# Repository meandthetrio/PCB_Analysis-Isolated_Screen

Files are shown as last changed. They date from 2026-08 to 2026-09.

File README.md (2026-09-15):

# PCB Analysis — WavetableController (Daisy Seed synth)

**Read this first.** This folder holds a completed design review of Trey's "WavetableController" board — an Electrosmith Daisy Seed–based wavetable synth controller, 2-layer, 165×102 mm, designed in KiCad 9. The board has been fabbed twice at JLCPCB and the physical boards mostly work. The analysis (all passes complete, 2026-08-13) found several real defects and produced a rev-2 plan.

**If you are Claude opening this fresh:** the authoritative output is [analysis/FINAL_REPORT.md](analysis/FINAL_REPORT.md) (tiered red flags + open questions for Trey), backed by the full findings ledger F-001…F-035 in [analysis/FINDINGS.md](analysis/FINDINGS.md). Do not re-derive anything before checking those. Methodology and which-file-is-truth rules are in [analysis/SOURCE_OF_TRUTH.md](analysis/SOURCE_OF_TRUTH.md).

## Folder contents

| Path | What it is |
|---|---|
| `WavetableController.kicad_pro` / `.kicad_sch` / `.kicad_pcb` | KiCad 9 design files, sent by Trey piecemeal (see provenance below) |
| `Manifold_Gerb_LedFix/` | The Gerbers + drill files actually sent to JLCPCB ("LedFix" round, 2nd proto). **Fab truth for copper.** |
| `ManifoldRe_BOM_NEW - Excel Format.xls` | JLCPCB-format BOM |
| `analysis/` | The full review: FINAL_REPORT, findings ledger, SOURCE_OF_TRUTH, PASS1–6 reports, REV2 OLED plan, routing CSVs extracted from Gerbers, board SVG, parser script. Has its own [README](analysis/README.md) index. |
| `screen mounting solution.md` | Mechanical mounting guide for the rev-2 Crystalfontz CFAL12864G-024W COG OLED (tape+gasket sandwich, plus 3D-printed bezel alternative) |

## Critical provenance warning

Trey sent files reluctantly and in stages: Gerbers+BOM first, then .pro/.sch, then the .kicad_pcb last. File mtimes are transfer times, not edit times. The `.kicad_pcb` in this folder matches the LedFix Gerbers ~97% **but contains NO GND pour** (only 5 keepout zones), while the fabbed B.Cu Gerber has a 164×100 mm filled pour covering 44/63 GND pads. It is a stale/wrong version — **never regenerate Gerbers from this copy.** Standing ask: get Trey's real working .kicad_pcb (the one that shows a filled B.Cu pour when opened). Where sch and pcb disagree (e.g. LED2 wiring), the pcb matches the fabbed boards, so the schematic is the outlier.

## Headline findings (details + evidence in analysis/)

- **Encoder push-buttons dead** — ENCL_CLICK / ENCR_CLICK have zero copper in the Gerbers (floating inputs; ENCR lands on a 3.3V-only Daisy pin). Fab-confirmed.
- **RGB LEDs triple-broken** — LED1/LED2 (CLS6B-FKW) are unplaced (missing from BOM, though the paste stencil expects them), reverse-biased via 300Ω to +9V_FILT (never light either polarity), and three LED pins sit on Daisy's 3.3V-only pins 24/25/30.
- **I2C has zero pull-ups in-design** — the ~203 mm bus relies entirely on the OLED module's onboard pull-ups (open question F-027 for Trey).
- **Duplicate refdes R21** — a layout-only 300Ω footprint at (170.1, 84.8) bridges /OLED_HOT–/+3V3_D in parallel with FB4 (Trey's noise-debug hack, on physical boards, not in schematic). Pick-and-place would put 300Ω where the 10Ω OLED damper belongs; breaks BOM/CPL matching.
- **0.1 mm traces board-wide** — exactly AT JLCPCB's 2-layer 1oz minimum (not below it), zero margin; carries the +3V3_D rail, I2C, SD, MIDI, USB. Recommend 0.2–0.25 mm. DRC min_track_width is 0.0 in the .kicad_pro, so KiCad won't flag them.
- **BOM refdes mismatch** — BOM's S1/S2 don't exist in the schematic (real refs are TAC_SWITCH_1/2, TAC_SHIFT_L1/R1 — note: underscore refs escape `[A-Z]+[0-9]+` regexes).
- 3 marginal fab violations (MK1 annular ring, P2 NPTH clearance, SW1 edge copper — the last is a deliberate notch, accepted). Power design: USB-C is data-only by design; 9V barrel → Schottky bridge → +9V_FILT (~8.3V).

**Open questions blocked on Trey:** F-014 (LED2 sch-vs-pcb, which is intended), F-027 (OLED module pull-up value), and the real .kicad_pcb with the GND pour.

## Rev-2 screen work (planning only, no design files changed)

[analysis/REV2_OLED_PLAN.md](analysis/REV2_OLED_PLAN.md): replace the two HiLetgo SSD1309 modules (boost-coil whine) with bare COG panels on 0.5 mm ZIF, independent I2C addresses 0x3C/0x3D. Two candidate panels:

- **Mono:** Crystalfontz CFAL12864G-024W (2.4", SSD1309) — needs 12.5–13.5V VCC, so a 15V adapter + ~13V LDO. Mounting solved in `screen mounting solution.md`.
- **Greyscale (user's preference):** no 2.42" greyscale panel exists anywhere. Best match is Raystar REX012864U / Winstar WEO012864U — 2.7" SSD1357, 16-level grey, VCC 8–10.5V (12V adapter + 10V LDO). **Unresolved geometry flag:** two 73 mm glasses = 146 mm side-by-side and conflict with the x≈165–200 audio-corridor keep-out. Fallback: stay mono, or 1.54" SSD1327.

Board changes either way: add 2.2k I2C pull-ups, remove J2/FB4/C14/C17/both R21s, use Daisy spare pads 22 & 28 for RES# and VCC_EN sequencing.

## Tooling notes

- **KiCad 9.0.9 (Linux / Claude Code on the web):** `kicad-cli` and the `pcbnew` Python module are on PATH. `.claude/hooks/session-start.sh` (a SessionStart hook) runs `tools/kicad_env_setup.sh` automatically in web sessions; run it by hand with `sudo tools/kicad_env_setup.sh` elsewhere. It installs the stock symbol/footprint libs and seed the user library tables (otherwise ERC/DRC add ~190 "library not found" warnings). `tools/kicad_check.sh` runs ERC, DRC, netlist, Gerber, SVG and PDF exports into `kicad_out/` (git-ignored) as a smoke test.
- **Freerouting 2.4.1 autorouter** is installed by the same setup script (needs Java 25, installed alongside the system Java 21; `freerouting` wrapper on PATH runs it headless with analytics off). `tools/autoroute.py IN.kicad_pcb OUT.kicad_pcb [--passes N]` does DSN export → route → SES import. It temporarily renames the duplicate R21, because the Specctra exporter refuses boards with duplicate refdes (an independent confirmation of that finding). On the stale checked-in board, 2 passes took 53 unrouted connections to 5. Remaining lib warnings name Trey's private libs (`Retroactive_Custom_Parts`, `Jack_3.5mm_CUI_RetroactiveCustom`, `SOP-6_...(RetroactiveCustom)`), which only exist on his machine; footprints are embedded in the `.kicad_pcb`, so they are harmless. Note `pcbnew.LoadBoard(...).Zones()` returns 0 here because the 6 keepout zones live inside footprints, not at board level.
- On Trey's Mac, KiCad 10.0.5 lives at `/Applications/KiCad.app` (kicad-cli at `Contents/MacOS/kicad-cli`; brew cask fails without sudo).
- `analysis/gerber_analyze.py` is the Gerber parser/net-matcher that produced the routing CSVs. Other scratch scripts (pcb_parse.py, pcb_audit.py, DRC/ERC reports) lived in a session scratchpad and may be gone — regenerate from gerber_analyze.py patterns if needed.
- Net names in the routing CSVs are geometrically inferred (anchored at Daisy pins, 6/6 validated on LED nets), not authoritative; `island_*` = unidentified copper.

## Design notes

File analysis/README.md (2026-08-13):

# Analysis folder index

Start here: **`FINAL_REPORT.md`** — the tiered red-flag summary, including the three open questions for Trey. Everything else is supporting material; no findings live only in this README.

## Reports
- `FINAL_REPORT.md` — final summary, Tiers 1–4, questions for Trey
- `FINDINGS.md` — full ledger (F-001…F-035) behind the summary
- `HIGH_LEVEL_PLAN.md` — the pass plan the review followed
- `SOURCE_OF_TRUTH.md` — methodology: which file is authoritative for what, verification rules
- `PASS1_FAB_CONSTRAINTS.md` … `PASS6_MECHANICAL.md` — per-pass detail (fab limits, power, connectivity, BOM, signals, mechanical)
- `REV2_OLED_PLAN.md` — OLED/I2C rev-2 planning

## Data files (derived, machine-generated)
Extracted from the fabbed Gerbers, with net names assigned by geometrically cross-referencing copper connectivity against the schematic netlist (anchored at Daisy Seed pins). Net attribution is inferred, not authoritative — `island_*` entries are copper the matcher could not identify.
- `routing_tracks.csv` — every track segment: layer, endpoints, width, length, net
- `routing_pads.csv` — pads: layer, position, shape, size, net
- `routing_vias.csv` — vias: position, drill, pad, net
- `wavetable_board.svg` — rendered board view from the Gerbers
- `gerber_analyze.py` — the parser/matcher script that produced the above

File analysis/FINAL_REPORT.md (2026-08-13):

# WavetableController — Final Red-Flag Report
**Date:** 2026-08-13 · **Scope:** Passes 0–6 complete (see `HIGH_LEVEL_PLAN.md`), 35 ledger entries (`FINDINGS.md`), all verified per `SOURCE_OF_TRUTH.md` — every measurement scripted, every threshold fetched and cited.
**Verification state:** 33 of 35 findings confirmed; 2 blocked on information only Trey has (marked ⏳ below). Nothing remains unverified-and-unflagged.

---

## Tier 1 — Defects in the working boards (physical, today)

**1. Encoder click switches are dead.** (F-007, fab-truth confirmed)
No copper exists at any of the four click-switch pad sites on either layer of the fabbed Gerbers. Both encoder push-inputs float. If firmware reads them, behavior is undefined. *Fix: route ENCL1.S1→pin 11, ENCR1.S1→pin 29 (pin 29 is 3.3V-only — never pull above 3V3).*

**2. The RGB LEDs are broken three ways.** (F-001/F-018/F-002/F-034)
(a) Not placed: the only SMD parts missing from the BOM — while the top-side paste stencil contains exactly their 12 apertures. (b) Wired to never light: permanently reverse-biased (anodes on GPIOs, cathodes toward +9V via 300Ω). (c) Hazardous if placed: 5.7–9V reverse across dice rated ~5V, and three of the six GPIOs (Daisy pins 24/25/30) are on the datasheet's 3.3V-only list — an avalanche event injects current into non-tolerant pins. *Fix: rewire GPIO→resistor→LED→GND per the Daisy reference (Fig 1.8), resize resistors for 3.3V, add LEDs to BOM.*

**3. The I2C/OLED subsystem stands on two hidden crutches.** (F-019 confirmed + F-027 ⏳)
The 203mm I2C bus has **zero pull-up resistors in the design** — it works only because of undocumented pull-ups presumed on the OLED module. And the +3V3_D rail feeding SD+OLED+MIDI has a single 100nF cap, with the SD card 109.5mm (~0.5Ω of 0.1mm trace) from it. Together these are the causal chain behind the OLED/I2C noise that was historically patched with a ferrite + 470µF + hand-added 10Ω. *Fix: explicit 2.2–4.7k pull-ups; 100nF+10µF at the SD connector; wider 3V3_D trunk. ⏳ Ask Trey what pull-ups the OLED module carries.*

## Tier 2 — Landmines that fire on the NEXT build (files as they stand)

**4. The `.kicad_pcb` in hand has no ground plane.** (F-006)
Provably not the file that made the working Gerbers (which contain a 164×100mm B.Cu pour this file cannot produce). Re-plot from it and you ship a board with 51 floating GND connections. *Fix: get Trey's real working file, or re-create the GND zone before any re-plot.*

**5. Duplicate refdes R21 → automated mis-build.** (F-013/F-025)
Two R21s on the PCB (300Ω LED resistor + 10Ω OLED damper); the BOM's only R21 line is 300Ω. Pick-and-place from this board puts **300Ω in the OLED's power feed** (30× intended). *Fix: rename the damper (e.g., R29), give it its own BOM line.*

**6. Board-level fixes were never back-annotated.** (F-020/F-014 ⏳)
The 10Ω OLED damper exists only in the PCB; the schematic doesn't know about it. LED2's pin-wiring differs between schematic and PCB (PCB matches the fabbed Gerbers; the schematic is the outlier). Any respin driven from the schematic silently reverts both. *⏳ Reconcile against Trey's current working files.*

**7. BOM S1/S2 can't be built.** (F-003)
An SMD 6×6mm tactile switch (C2835239) with no matching board position — the board's tactile switches are all through-hole. Stale line or diverged part choice; an assembler will flag or skip it.

## Tier 3 — Fab-margin risks (absorbed by tolerance so far)

**8. 3.85 meters of trace at exactly the 0.10mm minimum** (F-004/F-012) — zero margin against JLCPCB's ±20% width tolerance, including the 3V3_D power rail. Not a violation; the defining latent risk of the layout. *Widen to ≥0.2mm on respin; note 2oz copper would make 0.1mm illegal (min 0.16).* 
**9. Three marginal spec violations, fabbed OK twice** — MK1 annular ring 0.175mm vs 0.18 absolute min (F-016); USB-C footprint NPTH-to-copper 0.194 vs 0.20mm (F-008); SW1 edge copper in its deliberate notch, 0.0 vs 0.2mm — accepted (F-010). *Footprint edits when convenient; a stricter fab lot could reject any of them.*

## Tier 4 — Robustness & hygiene (JUDGMENT)

- **Headphone amp missing its datasheet-recommended ≥10µF bulk cap** on 3V3_A (F-031, TI SLOS314B cited; mid-rail bypass check passes).
- **No chassis mounting holes** — board hangs from panel hardware; confirm the enclosure plan (F-032).
- Long thin analog runs (up to 285mm @ 0.1mm) — fine as built, shorten on respin (F-030). USB pair asymmetry — benign at Full-Speed (F-028). SD card-detect half-wired, unusable by firmware (F-022). ERC hygiene: 13 missing no-connect flags + 2 PWR_FLAGs would take ERC to zero (F-024). Hand-assembly parts (incl. the 470µF noise-fix cap) exist on no list (F-026). Silk warnings = panel artwork, cosmetic (F-033). DRC minimums zeroed in the project file — set to JLC values so KiCad guards the margins (F-005).

## What passed (verified, cited)
Power-entry topology (9V within VIN 4–17V; D2–D5 bridge); AGND↔DGND tie; SD interface incl. reference-design 47K pullups; MIDI in/out exactly per 3.3V MIDI practice; all rails within IPC-2221 ampacity; via geometry (0.6/0.3mm, wide margin); all drill sizes; hole-to-hole spacing; copper spacing; courtyards (zero overlaps); mask consistency; BOM values (58/58 designators consistent).

## The three questions for Trey
1. Send the **current working `.kicad_pcb`** — the one that shows a filled bottom ground pour when opened (this copy has none).
2. **What pull-ups are on the OLED module?** (determines whether I2C stands on anything at all)
3. Is the **schematic or the PCB** right about LED2's wiring — and does your schematic have the 10Ω OLED damper the PCB carries as a second "R21"?

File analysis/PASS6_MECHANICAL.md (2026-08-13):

# Pass 6 — Mechanical & Assembly Report
**Date:** 2026-08-13 · **Truth checked:** `.kicad_pcb` geometry + Gerber paste/mask/silk + DRC baseline

## Board
165.1 × 101.6mm bounding box (matches the ~165×102 expectation), 1.6mm, outline is a polygon (not a plain rectangle — see SW1).

## F-010 RESOLVED: SW1 edge copper is deliberate
SW1 is a vertical **slide switch** (DigiKey 1101A4VQEA) at the top edge; its no-net anchor pads sit 0.41mm from the board's bounding box, but the Edge.Cuts **polygon notches inward** at the switch so the outline reaches the pads (DRC's 0.000mm). This is a deliberate edge-mount: the actuator needs the notch. Reclassified **JUDGMENT — accepted design deviation**: still technically below JLCPCB's 0.2mm copper-to-edge spec, fab-proven twice; expect occasional burrs/exposed copper at the notch. No action unless a fab rejects it.

## F-032 (NEW — JUDGMENT): no chassis mounting holes
Every NPTH on the board is a component alignment post: 5×1.2mm under each of the five 3.5mm jacks (25), 2.0mm at the barrel jack, 2×0.65mm at USB-C. There are **no M2.5/M3 mounting holes**. For a synth control surface this usually means the board hangs entirely from panel hardware (jack bushings, encoder nuts, switch bushings) — workable, but all mechanical stress from cable insertions transfers through solder joints and panel nuts. Confirm the enclosure plan; if the board isn't nut-mounted to a panel, this is a real gap.

## F-033 (NEW — JUDGMENT/cosmetic): silkscreen findings are panel artwork
The 143 silk warnings decompose as: 62 = front-silk **artwork polygons** (the 88 gr_polys — this board's front silk is the control-panel graphics) over copper, 37 = artwork reaching the board edge, 32 overlaps among art/refdes (ENCR1, TAC_SWITCH_2, LED2 etc.), 7 = SW1's back-silk over copper. Fabs clip silk on exposed pads automatically; over-masked-copper silk prints fine. Cosmetic — worth one visual check of the fab's silk preview on the next order, nothing more.

## F-034 (NEW — corroborates F-002): the stencil expects the missing LEDs
Paste flash counts: **F.Paste = 12 flashes — exactly the 12 pads of LED1+LED2** (the only top-side SMD parts); B.Paste = 192 (all other SMD, bottom side). So the top stencil and placement data anticipate the LEDs that the BOM omits — the assembly gap is physical, not just clerical: paste gets printed (if a top stencil was ordered) for parts that never arrive.

## Clean checks
- **Courtyard overlaps: zero** (severity-all DRC reported none) — PASS.
- **Mask layers consistent**: F/B mask flash counts (151/321) consistent with pad+via tenting config — PASS.
- **Connector accessibility**: jacks/encoders/switch all on top face with bushings at or near edges (panel-through design) — consistent with F-032's panel-mount assumption.
- Hole-to-hole, edge clearances (other than SW1), drill ranges: all covered and passed in Pass 1.

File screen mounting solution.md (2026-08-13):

# Screen Mounting Solution — Crystalfontz CFAL12864G-024W OLED

**Module:** [CFAL12864G-024W](https://www.crystalfontz.com/product/cfal12864g024w-128x64-2-4inch-white-oled-module) — 128×64 2.4" white OLED
**Context:** Bare chip-on-glass (COG) module mounted between a PCB and a metal enclosure with a display cutout.

## Key mechanical facts

| Property | Value |
|---|---|
| Glass outline | 60.5 × 37.0 mm |
| Thickness | 2.15 mm |
| Viewing area | 57.01 × 28.91 mm |
| Active area | 55.01 × 27.46 mm |
| Weight | 9.2 g |
| Connection | FPC ribbon tail into ZIF connector (TE 3-1734839-1 top-contact, or Hirose FH41-31S-0.5SH bottom-contact) |
| Mounting holes | **None** — cannot be screwed down |

## Mounting approach: tape + gasket sandwich

### 1. Adhesive tape to the PCB (primary attachment)
- Frame of thin double-sided adhesive on the PCB where the glass sits:
  - 3M 467MP / 468MP transfer tape (thin), or 3M VHB (adds cushioning)
- Keep-out under the active area — no components or vias under the glass, or add a spacer/foam pad to keep it flat.
- FPC tail folds around into the ZIF connector on the PCB.
- The tape IS the mount — this is how nearly every product using these glass modules does it.

### 2. Foam gasket between glass and metal panel
- Rectangular picture-frame gasket, ~0.5–1 mm compressible foam, around the display opening on the inside of the enclosure.
  - Poron is the classic choice; 3M double-coated foam tape (e.g. 4926) also works.
- When the enclosure closes, the foam lightly compresses against the glass face.
- Four jobs: takes up stack-height tolerance, prevents glass-to-metal contact (glass + rigid metal = cracked display), blocks light leakage around the window, keeps dust out.

### 3. Window sizing
- Bezel opening: bigger than viewing area (57.0 × 28.9 mm), smaller than glass outline (60.5 × 37 mm).
- ~**58 × 30 mm** hides the glass edges and the driver-chip strip while showing the full image.
- The active area is offset toward one side of the glass (driver IC + FPC take up one edge) — center the window on the *viewing area* from the datasheet drawing, not on the glass outline.

## Stack-height calculation

Measure: PCB top surface → inside face of enclosure panel.

```
gap − 2.15 mm (glass) = tape thickness under glass + compressed foam thickness above it
```

- If the gap is large: rigid spacer or 3D-printed carrier frame under the display, keep the foam layer thin.
- Target ~30–50% foam compression — gentle, even pressure only around the border of the glass, never concentrated on a corner.

## Cautions

- **Don't** rely on enclosure clamping alone — vibration lets the glass shift and the FPC fatigues.
- **Don't** hard-clamp the glass rigidly with no compliance — it needs the foam.
- Alternative for serviceability: small 3D-printed or machined bezel frame that captures the glass edges and screws to the PCB (detailed below). For one-offs / small runs, tape + Poron gasket is the proven answer.

## Alternative: 3D-printed bezel frame

A rectangular frame that screws to the PCB and captures the glass — serviceable (no adhesive), precisely located, and sets the correct height to the enclosure window. The glass drops into a pocket from behind; the front lip overhangs the glass edges; the frame screws to the PCB trapping the glass — always with thin foam in the sandwich, never plastic clamped hard on glass.

### Design dimensions

| Feature | Dimension | Notes |
|---|---|---|
| Glass pocket | 61.0 × 37.5 mm | +0.5 mm total clearance over the 60.5 × 37.0 glass; drop-in fit, never press-fit |
| Pocket depth | ~2.0 mm | Glass is 2.15 mm — lip pre-loads slightly onto foam instead of bottoming plastic-on-glass |
| Front lip opening | ~58 × 30 mm | ~1.5 mm overlap per side; larger than 57.0 × 28.9 viewing area so no image crop; hides driver-chip strip |
| FPC slot | Full ribbon width | In the pocket wall on the FPC edge (check datasheet drawing); round/chamfer edges so ribbon doesn't crease when folding to the ZIF |
| Foam | 0.5 mm Poron | Between lip and glass face, ideally also under the glass. Foam grips the display; plastic only sets geometry |
| Mounting | 4× corner bosses, M2 | Heat-set inserts (clean) or M2 self-tappers into 1.7 mm holes. Add matching M2 holes to the PCB around the display footprint |

- The active area is **offset** on the glass — model the opening relative to the viewing area per the datasheet mechanical drawing, not the glass outline.
- Nice extra: alignment pins or a raised rim on the front face that registers into the enclosure window cutout — the screen self-centers and PCB↔enclosure tolerance stacking disappears.

### Printing notes

- **Material:** PETG or ASA. PLA OK for prototypes but creeps under clamping load and softens in a warm enclosure.
- **Orientation:** bezel-face-down on a smooth plate — clean visible face, no supports needed for the pocket.
- **Tolerances:** FDM pockets come out 0.1–0.3 mm undersized. Print just the pocket as a quick test piece and confirm the glass drops in before printing the full frame.
- **Caution:** no plastic may press directly on glass anywhere — every contact on the display face goes through foam. Glass tolerates gentle distributed pressure, fails at hard point contacts.

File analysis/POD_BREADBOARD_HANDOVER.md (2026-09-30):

# Handover: Newhaven OLED breadboard test on a Daisy Pod

*Written 2026-09-30 for a new, separate firmware repo. Source of the decisions below:
`analysis/REV2_OLED_PLAN.md` §11 in the PCB_Analysis-Isolated_Screen repo.*

Copy this file, the Newhaven datasheet PDF (`NHD-2.7-12864WDW3-3.pdf`), and Trey's pin
list (`OLED_Pin_Connects_to_Newhaven.txt`) into the new repo's `docs/` folder.

---

## 1. What we are doing and why

**Project:** WavetableController, a Daisy Seed based synth controller (Trey's board).
Rev 1 uses a HiLetgo 2.42" SSD1309 OLED module over I2C. Its on-board boost converter
causes audible coil whine and couples noise into the audio path. Rev 2 replaces it.

**New screen:** Newhaven **NHD-2.7-12864WDW3** — 2.7" 128×64 white OLED module,
**SSD1322** controller (16-level grayscale), **4-wire SPI**, 1×20 pin 2.54 mm header.
It is a module on its own PCB, not bare glass.

**This phase:** prove the screen works with the Daisy platform before any PCB changes.
Concretely:

1. Wire the module to a **Daisy Pod** on a breadboard.
2. Write a small libDaisy program that initialises the SSD1322 over SPI and draws
   something recognisable (text / rectangle / test pattern).
3. Confirm the SPI pin assignment that the rev-2 board will use, unchanged.

The existing firmware's SSD1309 driver does **not** carry over. SSD1322 is a different
command set and a 4-bit-per-pixel framebuffer. libDaisy has no SSD1322 driver; its
`src/dev/oled_ssd1327.h` (also 4-bit grayscale) is the closest reference.

**Deliberate constraint:** the screen's five signal pins are **identical on the Pod and on
the rev-2 PCB**. The screen is the new/complex element, so it keeps fixed pins and the
simple things (encoders, buttons) move around it on the board. Do not "just use any free
pin" on the Pod — use the table in §3.

---

## 2. Power for this test (decided)

**Default jumpers, everything from 3.3 V.** Module as shipped: R4 closed, R5 open,
R7 open. Pin 2 (VDD) gets 3.3 V; the module's on-board boost makes the panel voltage.
Pins 3 and 15 stay open. Pin 18 (/SHDN) stays open (internally pulled high → boost on).

Datasheet (p.6, Default Jumper Setting): VDD 3.0–3.5 V, **IDD 345 mA typ / 375 mA max
at 100 % pixels on**.

We could not find a published current limit for the Seed's 3V3 output (its datasheet
doesn't state one). To keep the test safe regardless:

- Power the Pod from a **USB wall adapter ≥ 1 A**, not a laptop USB port (500 mA budget
  is already exceeded by Seed + Pod + screen).
- **Do not run the all-pixels-on test (0xA5).** That is the 375 mA case. Normal UI
  content (10–30 % pixels) draws roughly proportionally less.
- **Start with master contrast reduced**: command `0xC7` with data `0x03` (¼ output)
  instead of the datasheet's `0x0F`. Raise later once current is known.
- Draw text / outlines, not filled screens.
- Feel the Seed's regulator after a minute. Warm is fine; too hot to hold is stop.
- Decouple pins 2→1 at the header: 100 nF + 10–100 µF. The boost pulls current in bursts
  and breadboard rails are poor.

Later (not this test): jumper option #2 feeds the panel from an external 14.5–15.5 V on
pin 15 and disables the boost. That is the rev-2 noise fix; it is a separate experiment.

---

## 3. Wiring: Newhaven module → Daisy Pod (20 pins)

From the datasheet serial-interface pin table (p.4) and interface-select table (p.5).
Seed pin = the 40-pin physical numbering on the Seed / Pod headers.

| Module pin | Symbol | Connect to | Notes |
|---|---|---|---|
| 1 | VSS | GND | |
| 2 | VDD | **3.3 V** (Seed pin 38, 3V3_D) | + decoupling caps, see §2 |
| 3 | NC (BC_VDD) | open | |
| 4 | D/C | **D11** = Seed pin 12 (PB8) | 0 = command, 1 = data |
| 5 | VSS | GND | |
| 6 | VSS | GND | |
| 7 | SCLK | **D8** = Seed pin 9 (PG11, SPI1_SCK) | |
| 8 | SDIN | **D10** = Seed pin 11 (PB5, SPI1_MOSI) | |
| 9 | NC | open | |
| 10 | VSS | GND | |
| 11 | VSS | GND | |
| 12 | VSS | GND | |
| 13 | VSS | GND | |
| 14 | VSS | GND | |
| 15 | NC (VCC) | open | (15 V input, only with jumper option #2) |
| 16 | /RES | **D12** = Seed pin 13 (PB9) | active low; optional 10 k pull-down to GND |
| 17 | /CS | **D7** = Seed pin 8 (PG10, SPI1_NSS) | active low |
| 18 | /SHDN | open | internally pulled high |
| 19 | BS1 | GND | BS1 = 0, BS0 = 0 → 4-wire SPI |
| 20 | BS0 | GND | |

No pull-up resistors are needed (SPI is push-pull). Nothing above 3.3 V anywhere.

**These five pins are the rev-2 board assignment too:** D7 /CS, D8 SCLK, D10 SDIN,
D11 D/C, D12 /RES. On the board, /ENCR_A, /ENCR_B and /ENCL_CLICK move off D7/D8/D10
to make room.

---

## 4. Daisy Pod pin usage (Pod Rev 3/4 on Seed Rev 3/4)

From libDaisy `src/daisy_pod.cpp`, `src/daisy_seed.h`, `src/per/uart.cpp`.
Seed digital pin numbering: D0–D14 = physical pins 1–15; D15–D30 = physical pins 22–37.

### Used by the Pod

| libDaisy | STM32 | Seed pin | Pod function |
|---|---|---|---|
| D13 | PB6 | 14 | Encoder click (also USART1_TX, unused: no MIDI out) |
| D14 | PB7 | 15 | MIDI in (USART1_RX) |
| D15 | PC0 | 22 | Knob 2 (ADC) |
| D17 | PB1 | 24 | LED 2 red |
| D18 | PA7 | 25 | LED 1 blue |
| D19 | PA6 | 26 | LED 1 green |
| D20 | PC1 | 27 | LED 1 red |
| D21 | PC4 | 28 | Knob 1 (ADC) |
| D23 | PA4 | 30 | LED 2 blue |
| D24 | PA1 | 31 | LED 2 green |
| D25 | PA0 | 32 | Encoder B |
| D26 | PD11 | 33 | Encoder A |
| D27 | PG9 | 34 | Button 1 |
| D28 | PA2 | 35 | Button 2 |
| — | — | 16–19 | Audio in/out L/R (codec) |
| D29 / D30 | PB14 / PB15 | 36 / 37 | USB D− / D+ |

Fixed: pins 20 and 40 GND, 21 3V3_A, 38 3V3_D, 39 VIN.

### Free on the Pod

| libDaisy | STM32 | Seed pin | Note |
|---|---|---|---|
| D0 | PB12 | 1 | USB_ID, usable GPIO |
| D1–D6 | PC11, PC10, PC9, PC8, PD2, PC12 | 2–7 | SDMMC pins (no SD slot on Pod) |
| **D7** | **PG10** | 8 | **SPI1_NSS → screen /CS** |
| **D8** | **PG11** | 9 | **SPI1_SCK → screen SCLK** |
| D9 | PB4 | 10 | SPI1_MISO (unused; screen is write-only) |
| **D10** | **PB5** | 11 | **SPI1_MOSI → screen SDIN** |
| **D11** | **PB8** | 12 | **→ screen D/C** |
| **D12** | **PB9** | 13 | **→ screen /RES** |
| D16 | PA3 | 23 | free (ADC-capable) |
| D22 | PA5 | 29 | free (3.3 V-only pin) |

The Pod's knobs, buttons, encoder, LEDs and MIDI are all untouched by the screen wiring.

---

## 5. SSD1322 / firmware facts needed to write the program

### libDaisy transport already fits

`libDaisy/src/dev/oled_ssd130x.h` contains `SSD130x4WireSpiTransport`. Its **defaults are
exactly our pins**: SPI1, SCLK PG11 (D8), MOSI PB5 (D10), NSS PG10 (D7), hardware NSS,
TX-only, 8-bit, mode 0. Only `pin_config.dc` and `pin_config.reset` need overriding to
PB8 (D11) and PB9 (D12). Its `SendCommand()` / `SendData()` handle the D/C line. Reuse it;
write only the SSD1322 init and framebuffer code. Set `baud_prescaler` to `PS_32` or
slower to start (few MHz); SSD1322 SPI limit is ~10 MHz.

### Reset timing (datasheet p.15)

/RES low ≥ 200 µs → high → wait ≥ 200 µs → send commands. (The libDaisy transport's
`Init()` does 10 ms each side, which is fine.)

### Init sequence (datasheet p.15, Newhaven's own routine, verbatim)

```
0xAE              display OFF
0xB3 0x91         clock divide / oscillator
0xCA 0x3F         MUX ratio 64
0xA2 0x00         display offset
0xAB 0x01         function select: internal VDD regulator
0xA0 0x16 0x11    re-map (nibble remap + dual COM mode)
0xC7 0x0F         master contrast   ← use 0x03 for the first test (see §2)
0xC1 0x9F         contrast current
0xB1 0xF2         phase length
0xBB 0x1F         pre-charge voltage
0xB4 0xA0 0xFD    VSL / display enhancement
0xBE 0x04         VCOMH
0xA6              normal display
0xAF              display ON
```

Then to write pixels:

```
0x15 0x1C 0x5B    column address window 28..91
0x75 0x00 0x3F    row address window 0..63
0x5C              write RAM, then stream data bytes
```

### Framebuffer format (derived from the datasheet mechanical drawing, Detail A; verify
against Newhaven's example code at github.com/newhavendisplay before trusting it)

- The SSD1322 has 480 segments × 128 rows of RAM; this panel uses 256 segments × 64 rows,
  mapped at segments 112–367 → column addresses 28–91 (`0x1C`–`0x5B`). Each column address
  is 4 segments = 2 bytes.
- The panel wires **2 segments per visible pixel** (drawing: "Segment 112,113 = Column
  128", "Segment 366,367 = Column 1"). So one **byte = one pixel**, both nibbles the same
  4-bit grey value. `0xFF` = full white, `0x00` = off.
- Frame = 64 rows × 128 bytes = **8192 bytes**. Send it as data after `0x5C`.
- Note the segment order is reversed relative to column number in the drawing (segment
  112 = column 128). The `0xA0 0x16` remap in the init handles orientation; if the image
  comes out mirrored, that's the byte to change (bit A[1] column remap, A[4] COM scan).

### Other commands worth knowing (p.8–10)

- `0xA4` all off / `0xA5` all on (avoid, see §2) / `0xA6` normal / `0xA7` inverse.
- `0xFD 0x12` unlock (default is unlocked; `0xFD 0x16` locks).
- Full SSD1322 datasheet: http://www.newhavendisplay.com/app_notes/SSD1322.pdf

---

## 6. Suggested test program steps

1. Init transport (pins above), run reset + init with master contrast `0x03`.
2. Clear RAM: set window, `0x5C`, send 8192 × `0x00`.
3. Draw a 1-pixel border rectangle and a diagonal line. Confirms orientation, window
   bounds, and byte→pixel mapping in one image.
4. Draw text (port the 6×8 font from libDaisy's `oled_ssd130x` / `hid/disp` or Newhaven's
   example).
5. Only after the above: brief grayscale ramp (16 bars) at low master contrast.
6. Use Pod Button 1 to toggle display ON/OFF (`0xAF`/`0xAE`) and Knob 1 for contrast
   (`0xC1 n`) — cheap way to explore current draw with a meter on the 3.3 V line.

Suggested repo layout (standard Daisy):

```
<repo>/
  libDaisy/            git submodule: https://github.com/electro-smith/libDaisy
  PodOledTest/
    PodOledTest.cpp
    Makefile           TARGET=PodOledTest, CPP_SOURCES=PodOledTest.cpp,
                       LIBDAISY_DIR=../libDaisy, include $(LIBDAISY_DIR)/core/Makefile
  docs/                this file + datasheet + Trey's pin list
  .vscode/             copy from electro-smith/DaisyExamples
```

Toolchain: Electro-Smith's Daisy Toolchain installer (arm-none-eabi-gcc, make,
dfu-util, openocd) + VS Code C/C++ and Cortex-Debug extensions. Flash with
`make program-dfu` (Seed in DFU: hold BOOT, press RESET, release BOOT).

---

## 7. What this test is NOT

- Not a noise test. The boost converter is running in this configuration; noise
  evaluation needs jumper option #2 (external 15 V) and is a later experiment.
- Not the final driver. Once pixels are proven, the driver gets written properly
  (DMA, framebuffer class, libDaisy `OledDisplay` template) in the main firmware.

## 8. Open items carried from the plan

- 15 V supply scheme for the rev-2 board (adapter → bridge gives ~14.3 V, below the
  module's 14.5 V minimum).
- Whether the LED-drive redesign frees Seed pins (would give back two ADCs).
- /CS on D7: hardware NSS vs software-driven GPIO. Same pin either way; firmware choice.
- Seed 3V3 output current limit: unverified. If a datasheet copy is available, check it.

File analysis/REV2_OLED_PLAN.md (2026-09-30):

# Rev 2: OLED Display Redesign — Plan & Discussion Notes

*Compiled 2026-08-12 from design discussion. Companion to the rev-1 analysis reports in this folder.*
*Status: DISCUSSION ONLY — no PCB files have been modified.*

---

## 1. What we're doing and why

**Current state:** One HiLetgo 2.42" SSD1309 OLED module plugs into the 4-pin header J2.
The module is a mini-PCB with the screen glass glued on, plus a boost converter that
generates the panel's ~13V internally from 3.3V.

**Problem:** The boost converter is the noise villain, two ways:

1. **Audible buzz (coil whine):** the booster chops current through a tiny coil tens of
   thousands of times per second. The coil vibrates like a tiny speaker; pitch changes
   with screen content; the steel enclosure acts as a soundboard.
2. **Audio-path noise:** the booster draws power in sharp gulps that travel backward
   into the board's power system, where the audio circuits can pick them up. This is
   not hypothetical — rev 1 carries the scar tissue (a layout-only 10Ω resistor hack
   at the OLED power feed, plus a 470µF capacitor) from debugging exactly this.

**Rev-2 approach ("option B"):** Replace the module with a **bare glass panel** —
Crystalfontz **CFAL12864G-024W** (2.42" 128x64 white, same SSD1309 controller, 31-pin
flex ribbon tail). No boost converter anywhere. The panel's high voltage comes from the
power input, stepped down by a **linear regulator** — a valve, not a chopper. Nothing
switches, so nothing can buzz, and nothing gulps, so nothing couples into the audio.

- Datasheet: https://www.crystalfontz.com/products/document/3707/CFAL12864G024Wv1.1.pdf
- Demo code: https://github.com/crystalfontz/CFAL12864G_and_CFAL12864K

**Does the linear regulator make noise?** Practically none. It never switches — it
throttles ~14V down to 13V continuously and turns the difference into a trivial amount
of heat (no heatsink needed at ~20–50mA). Its intrinsic electrical noise is millionths
of a volt on a wire that only feeds the screen. Linear regulators are what audio
designers use *when they want quiet*. The 15V wall adapter is itself a switcher, but it
lives outside the box, switches steadily (not content-dependent), and its output is
cleaned twice (entry caps, then the regulator) before touching anything.

---

## 2. The power problem (IMPORTANT — the plan's premise needed correcting)

The original option-B brief said "feed the panel from the existing +12V rail; 12.0V is
at the low edge of spec." **Both halves are wrong:**

- **This board has no 12V rail.** Power nets are +9V_FILT, +5V_USB, +3V3_A, +3V3_D.
  The 9V barrel input goes through the Schottky bridge (D2–D5, ~0.7V drop) → ~8.3V.
- **The datasheet specs panel VCC at 12.5V min / 13.0V typ / 13.5V max** (p.7).
  12.0V is *below minimum*, not "the low edge."

**The fix:** change the wall adapter **9V → 15V**, add a **~13.0V linear regulator**
for the screen branch:

```
15V barrel → bridge (−0.7V) → ~14.3V → linear reg → 13.0V → ferrite bead + caps → screen VCC
```

Checked against the board:
- Daisy Seed VIN max is 17V, so 14.3V at the rail is fine (verify against current
  Daisy datasheet rev before committing).
- Dropout budget is only ~1.3V, so it must be a true LDO (AZ1117-ADJ class is fine),
  NOT an LM317 (needs ~2V of headroom).
- Screen draws 15–22mA at 50% pixels (datasheet); budget ~50mA worst case; size the
  regulator ≥150mA and forget about it.
- Don't go to an 18V adapter — bridge output ~17.3V would exceed Daisy's VIN max.
- The bridge makes the jack polarity-agnostic; the adapter swap is a label change +
  the new regulator. Update enclosure power labeling.

**One-way isolation still matters:** even without the booster, the screen's row-scan
current flutters with content at frame-rate harmonics (in the audio band). The ferrite
bead + 100µF at the connector fences that off from the rest of the board.

---

## 3. How the bare panel physically connects

The ribbon on the glass is a thin flex strip with 31 exposed metal fingers — not a
plug. It mates with a surface-mount **ZIF connector** ("zero insertion force") soldered
on the PCB: flip open the latch, slide the ribbon in, close the latch. Screen is
replaceable by unclipping. All support circuitry that used to live on the HiLetgo
mini-board moves onto our PCB, clustered around the ZIF connector.

**Candidate connectors** (31-pos, 0.5mm pitch):
- Hirose FH41-31S-0.5SH (bottom contact)
- TE 3-1734839-1 (top contact)

**⚠ The two genuinely risky steps (neither is circuit design):**

1. **Contact orientation.** The ribbon's contacts must face the connector's contacts.
   The datasheet drawing (p.4) shows the stiffener on the rear face / contacts on the
   viewer face at the tip, but the right connector flavor depends on how the tail folds
   in the enclosure stack. **Buy the panel and BOTH connector variants first, mock the
   fold with real parts against the enclosure, then finalize the footprint.**
2. **Reach.** Usable tail length ≈ 18mm after bend allowances (22.3mm total, keep
   ≥2mm flat off the glass, bend radius ≥1.5mm). The ZIF must sit almost directly
   behind the screen window. **Measure the face-to-board stack height before placing
   anything — this is the go/no-go input for the whole layout.**

Panel mechanicals: glass 60.5 × 37.0 × 2.15mm; active area 55.01 × 27.49mm; viewing
area 57.01 × 28.91mm. Panel mounts to the enclosure face with a bezel/adhesive frame.
Keep the exposed driver ledge on the glass shaded (it's light-sensitive, datasheet
p.11) — a windowed steel face does this naturally.

---

## 4. Complete pin-by-pin wiring table (I2C mode, single screen, address 0x3C)

From the CFAL12864G-024W datasheet pin function table (p.5–6) + application circuit
(p.6), cross-checked against the board's nets. **GND** = plain wire to ground.
**3.3V** = existing +3V3_D rail. **13V** = new regulated screen supply.

| Pin | Goes to | Notes |
|-----|---|---|
| 1 | GND | |
| 2 | GND | Main screen ground (VSS) |
| 3–10 | nothing | Leave unconnected (8 pins) |
| 11 | 3.3V | Logic power (VDD). Local caps: 100nF + 2.2µF to GND |
| 12 | 3.3V | Strap BS1=1 … |
| 13 | GND | … strap BS2=0. Together = "speak I2C" |
| 14 | nothing | Leave unconnected |
| 15 | GND | CS# — always enabled |
| 16 | Daisy spare pad (22 or 28) | RES# reset wire + 10k resistor to GND (holds screen in reset until firmware releases it) |
| 17 | GND | D/C# acts as address select → 0x3C, **same address the HiLetgo uses** — firmware address unchanged |
| 18 | GND | R/W# — required low in I2C mode |
| 19 | GND | E/RD# — required low in I2C mode |
| 20 | Daisy pad 12 (I2C_SCL) | Clock — same Daisy pin the HiLetgo SCL uses today |
| 21 | tie to pin 22 | D1+D2 joined… |
| 22 | …and to Daisy pad 13 (I2C_SDA) | …together they are the data line — same Daisy pin as today |
| 23–27 | GND | Unused data pins D3–D7, datasheet says tie low |
| 28 | 1MΩ 1% resistor to GND | IREF brightness-current set. Formula (VCC−3V)/10µA at 13V → 1MΩ |
| 29 | 1µF capacitor to GND | VCOMH reservoir (datasheet lists "C4"=1.0µF — its C3/C4 labeling has a typo; cross-check against Crystalfontz's own breakout for this panel) |
| 30 | 13V | Panel power (VCC). Local caps: 100nF ceramic + ≥100µF bulk to GND |
| 31 | GND | |

**Two parts not on any pin:** 2.2k pull-up resistors from SCL→3.3V and SDA→3.3V.
**Rev 1 has ZERO I2C pull-ups in-design (finding F-027)** — the HiLetgo module was
silently providing them. A bare panel provides nothing. **Without these two resistors,
rev 2 is dead on arrival.**

**Sanity totals:** 3 signal wires to the Daisy (pads 12 + 13 unchanged, + 1 spare pad
for reset) · 13 pins straight to ground · 2 pins to 3.3V · 2 pins with a single part ·
2 power pins with local caps · 9 pins empty.

**Optional but recommended — VCC power switch:** a high-side P-FET on the 13V branch
(gate pulled up = default off) driven by the *other* spare Daisy pad. Reason: the 13V
comes up before the Daisy's 3.3V, which is backwards from the SSD1309's preferred
VDD-then-VCC sequencing, and the datasheet warns about cutting power with VCC live
(p.10). Lets firmware sequence power correctly and hard-power-cycle the screen.
Note: pads 22 + 28 are the board's LAST spare pins (also the last spare ADCs) —
using both forecloses future pots/CV inputs; sign off deliberately.

---

## 5. What gets REMOVED from rev 1

- **J2** (4-pin OLED header) and its Retroactive_2.42_OLED_I2C footprint
- The entire OLED_HOT power subsystem: **FB4, C14 (470µF radial), C17 (100nF),
  R21 (10Ω)** — and the duplicate layout-only 300Ω "R21" hack at (170.1, 84.8).
  Side effect: resolves rev-1 findings F-013 / F-020 / F-025 (duplicate refdes,
  PCB-only damper, BOM/CPL collision).
- The schematic's "OLED RC FILT" block

## 6. BOM additions

2× ZIF connector candidates (buy both flavors as samples, use one) · LDO + set
resistors + its caps · P-FET + 2 resistors (optional VCC switch) · 1MΩ 1% · 1µF ·
2× 2.2µF · 2× 100nF · 100µF · ferrite bead(s) · 2× 2.2k pull-ups · 10k pull-down ·
optional 0.5A polyfuse on the screen branch (datasheet-recommended, p.10) ·
**15V wall adapter** (replaces 9V).

## 7. Layout guidance

- Board outline: x 89.6–254.7, y 61.1–166.0 (165 × 105mm). All rear-panel I/O along
  top edge.
- **Keep display power + I2C out of the center audio corridor (x≈165–200)** — audio
  jacks top-center, MAX9814 mic preamp dead center, Daisy + headphone amp bottom
  center. Rev 1 put the OLED feed *in* this corridor; rev-1 finding F-019 fingered it
  as the debugged noise path. Open real estate: x≈115–155 and x≈180–230 at y≈85–110.
- Put the 13V regulator near the existing bridge/filter area (x≈147–156, y≈78–90),
  run the filtered feed to the ZIF with the bead + bulk *at the connector*.
- New traces: ≥0.25mm signals, ≥0.5mm power. Do NOT inherit rev 1's 0.1mm
  at-JLC-minimum widths for new work.
- ZIF placement rule: connector within ~√(18² − h²) mm of the panel's bottom-edge
  projection, where h = face-to-board standoff in mm. At h=10mm → ~15mm reach. If the
  board sits >~15mm behind the face, the tail won't reach → extender FPC or rethink.

## 8. Firmware impact

- Same driver (SSD1309), same I2C address (0x3C), same Daisy pins → existing code
  carries over.
- New: drive RES# high after boot (release reset) before init; sequence VCC_EN after
  init if the P-FET is used.
- Keep the existing 0xD5 clock / 0xD9 precharge init tweaks (harmless, no longer
  load-bearing). No contrast compensation needed at 13.0V.
- Datasheet recommends periodic re-init/refresh as catastrophic-noise recovery (p.11)
  — cheap insurance in a synth EMI environment.

## 9. Open questions / to-do before schematic capture

1. **Enclosure CAD:** screen window center coordinates + face-to-board stack height
   (go/no-go for tail reach).
2. **Connector orientation:** settle with physical panel + both connector samples.
3. **Supply logistics:** 9V→15V adapter change acceptable? Update labeling.
4. **Verify** Daisy VIN 17V max against current Electrosmith datasheet rev.
5. Bundle the standing rev-1 fixes into this spin: encoder click routing (F-007),
   LED drive redesign (F-018), GND pour file provenance (F-006), 0.1mm trace widths.

## 10. Corrections to the original brief (for the record)

- The brief said the board hosts **two** displays sharing a bus at 0x3C/0x3D.
  The board has exactly **one** display header (J2) and rev 2 is **one screen** —
  confirmed in discussion. All dual-address strapping in the brief is moot; pin 17
  simply ties to GND.
- The brief's "+12V rail / 12.0V acceptable" premise was wrong on both counts
  (see §2).

---

## 11. Screen change: Newhaven NHD-2.7-12864WDW3 (supersedes §1–§4 where they conflict)

*Added 2026-09-29. The Crystalfontz bare-glass panel in §1–§4 has been replaced by the
Newhaven NHD-2.7-12864WDW3 module (datasheet rev 6, 07/31/2024). Status: DISCUSSION
ONLY — no design files modified.*

### 11.1 What is different

| | Crystalfontz plan (§1–§4) | Newhaven NHD-2.7-12864WDW3 |
|---|---|---|
| Controller | SSD1309, 1-bit | **SSD1322**, 16-level grayscale, different command set |
| Interface | I2C @ 0x3C | **SPI (3/4-wire) or 8-bit parallel — no I2C** |
| Connection | bare glass, 31-pin FPC into ZIF | **module PCB, 1×20 pin 2.54mm header** |
| Panel power | 13.0V from our LDO | on-board boost from 3.3V (default), or **14.5–15.5V into pin 15** (jumper option #2, R4 open / R7 closed) |
| Logic power | 3.3V | 3.0–3.5V. Default jumpers: up to 375mA @ 100% on. Option #2: ~0.3mA + 60–70mA @ 15V on VCC |

Consequences for the plan:

1. **Firmware:** the SSD1309 driver does not carry over. libDaisy has no SSD1322 driver;
   its `oled_ssd1327` (also 4-bit grayscale) is the closest starting point. Newhaven's
   init sequence is on datasheet p.15. Visible 128 columns sit at an offset inside the
   controller's 256-column RAM (mechanical drawing, Detail A) — copy the column/row window
   from Newhaven's example code.
2. **Pin count:** 4-wire SPI needs 5 Daisy pins (SCK, MOSI, CS, D/C, RES) vs 3 for I2C.
   See §11.2.
3. **Power:** the default (on-board boost) reintroduces exactly the switcher the rev-2
   brief set out to remove. Bypassing it (option #2) needs **14.5V minimum** on pin 15,
   but the §2 scheme (15V adapter → bridge → ~14.3V → LDO) can't reach that. Open — see §11.4.
4. **Mechanical:** §3 (ZIF orientation, tail reach) and `screen mounting solution.md` no
   longer apply. The module has its own PCB and header; mount per the datasheet
   mechanical drawing (bezel redesign rev 3, 2021).
5. **§5 removals and §6 BOM** still apply in spirit (J2, OLED_HOT filter block go away),
   but the ZIF, IREF/VCOMH parts and the I2C pull-ups are all dropped.

### 11.2 Daisy pin budget (from the rev-1 schematic netlist)

Physical Seed pin numbers; `D#` is the libDaisy name.

- **Free in rev 1:** pin 1 (D0, USB_ID — usable GPIO), pin 22 (D15/ADC0), pin 28 (D21/ADC6).
- **Freed by removing J2:** pin 12 (D11, /I2C_SCL), pin 13 (D12, /I2C_SDA).
- Total: 5 → enough for bit-banged SPI with no moves, but bit-banging a 4KB grayscale
  frame on the audio core with no DMA is a poor trade. Use hardware SPI1.

**Hardware SPI1 pins are all occupied in rev 1:**

| Pin | libDaisy | SPI1 role | rev-1 net |
|---|---|---|---|
| 8 | D7 | NSS | /ENCR_A |
| 9 | D8 | SCK | /ENCR_B |
| 10 | D9 | MISO | /TAC_SHIFT_R |
| 11 | D10 | MOSI | /ENCL_CLICK |

**DECISION (2026-09-29): one pin assignment, identical on the Pod breadboard and the
rev-2 board.** The screen is the new, complex element; the encoders/switches are simple
and move around it. This also matches Trey's pin list exactly.

| Module pin | Signal | Daisy | Seed pin | Notes |
|---|---|---|---|---|
| 1, 5, 6, 10–14 | VSS | GND | 20/40 | |
| 2 | VDD | 3V3 | 38 | local 100nF + ≥4.7µF. Breadboard with boost active: separate 3.3V supply ≥400mA |
| 3 | NC (BC_VDD) | — | | leave open |
| 4 | D/C | **D11 (PB8)** | 12 | ex-I2C_SCL |
| 7 | SCLK | **D8 (PG11, SPI1_SCK)** | 9 | |
| 8 | SDIN | **D10 (PB5, SPI1_MOSI)** | 11 | |
| 9 | NC | — | | leave open |
| 15 | NC (VCC) | — / 15V branch | | open with default jumpers; 15V only with jumper option #2 (ferrite + 100nF + ≥100µF at header) |
| 16 | /RES | **D12 (PB9)** | 13 | ex-I2C_SDA; 10k pull-down to GND |
| 17 | /CS | **D7 (PG10, SPI1_NSS)** | 8 | hardware NSS or software-driven, firmware's choice |
| 18 | /SHDN | — | | leave open (internally pulled high) |
| 19 | BS1 | GND | | BS1=0, BS0=0 → 4-wire SPI |
| 20 | BS0 | GND | | |

All five signal pins are free on the Pod today; on the board D11/D12 free up when J2 goes.

**Board nets that move in rev 2 (3):**

| Net | From | To | Note |
|---|---|---|---|
| /ENCR_A | pin 8 (D7) | **pin 1 (D0, PB12)** | USB_ID pin, plain GPIO |
| /ENCR_B | pin 9 (D8) | **pin 22 (D15, PC0)** | was spare ADC0 |
| /ENCL_CLICK | pin 11 (D10) | **pin 28 (D21, PC4)** | was spare ADC6; unrouted in rev 1 (F-007), needs re-routing anyway |

/TAC_SHIFT_R stays on pin 10 (D9 = SPI1_MISO, unused; the peripheral is write-only).

Cost: all three rev-1 spares are consumed, including both remaining ADCs (the §4 warning
stands). If the LED-drive redesign (F-018) moves the six LEDs to a driver chip, pins
24–27/30/31 free up again — decide the two together.

*Rejected alternative, for the record:* keeping the three GPIO lines (D/C, /RES, /CS) on the
board's spares (pins 1/22/28) and moving only 2 nets. Same pin cost, one fewer net move,
but different pin configs on breadboard vs board — rejected to keep the screen's wiring a
constant between the two.

VDD note from Trey's review: with default jumpers (boost active) the module can draw up to
375mA from a Seed 3V3 regulator with no published limit (F-021). Fine once on jumper
option #2 (~0.3mA on VDD); on the breadboard feed VDD from a separate supply.

SPI clock: keep ≤ 4MHz on the breadboard; SSD1322 limit is ~10MHz. Signal traces ≥0.25mm
per §7, kept out of the centre audio corridor.

### 11.3 Breadboard bring-up with a Daisy Pod

Standalone handover for the firmware repo: `analysis/POD_BREADBOARD_HANDOVER.md`.

**Pod pin usage** (libDaisy `daisy_pod.cpp` Rev 3/4 table, `daisy_seed.h` port map,
`uart.cpp` USART1 pins). Physical = Seed 40-pin numbering (D0–D14 = pins 1–15,
D15–D30 = pins 22–37).

| libDaisy | STM32 | Seed pin | Pod function |
|---|---|---|---|
| D13 | PB6 | 14 | Encoder click (also USART1_TX — unused, no MIDI out) |
| D14 | PB7 | 15 | MIDI in (USART1_RX) |
| D15 | PC0 | 22 | Knob 2 (ADC) |
| D17 | PB1 | 24 | LED 2 red |
| D18 | PA7 | 25 | LED 1 blue |
| D19 | PA6 | 26 | LED 1 green |
| D20 | PC1 | 27 | LED 1 red |
| D21 | PC4 | 28 | Knob 1 (ADC) |
| D23 | PA4 | 30 | LED 2 blue |
| D24 | PA1 | 31 | LED 2 green |
| D25 | PA0 | 32 | Encoder B |
| D26 | PD11 | 33 | Encoder A |
| D27 | PG9 | 34 | Button 1 |
| D28 | PA2 | 35 | Button 2 |
| — | — | 16–19 | Audio in/out L/R |
| D29/D30 | PB14/PB15 | 36–37 | USB D−/D+ |

Fixed: 20/40 GND, 21 3V3_A, 38 3V3_D, 39 VIN.

**Free on the Pod:**

| libDaisy | STM32 | Seed pin | Note |
|---|---|---|---|
| D0 | PB12 | 1 | USB_ID, usable GPIO |
| D1–D6 | PC11, PC10, PC9, PC8, PD2, PC12 | 2–7 | SDMMC pins, no SD slot on the Pod |
| **D7** | **PG10** | 8 | **SPI1_NSS** |
| **D8** | **PG11** | 9 | **SPI1_SCK** |
| D9 | PB4 | 10 | SPI1_MISO (unused by screen) |
| **D10** | **PB5** | 11 | **SPI1_MOSI** |
| D11 | PB8 | 12 | I2C1_SCL |
| D12 | PB9 | 13 | I2C1_SDA |
| D16 | PA3 | 23 | ADC-capable |
| D22 | PA5 | 29 | 3.3V-only pin |

The whole SPI1 block D7–D10 plus D11/D12 is uncommitted on the Pod, so the §11.2
assignment (D7/D8/D10/D11/D12) wires up identically on the Pod with no Pod control
touched. Do not use D15/D21 (pins 22/28) on the breadboard — those are the Pod's knobs.

1. **Default jumpers first** (on-board boost, 3.3V only). Power VDD from a separate 3.3V
   supply able to source ≥400mA — not the Seed's 3V3 pin. Common all grounds.
2. Wire exactly per the §11.2 table. Optionally /SHDN → D16 (free on the Pod only) so
   firmware can kill the boost while audio plays and the difference can be heard.
3. Firmware: /RES low ≥200µs, release, wait ≥200µs, send the p.15 init. Test with 0xA5
   (all pixels on) before real graphics.
4. **Then** move the 0Ω jumper R4 → R7 (option #2), feed 15.0V into pin 15 from a bench
   supply (3.3V up first, 15V second) and confirm the panel is quiet enough without the
   boost before committing the board to that scheme.

### 11.4 Open questions (add to §9)

6. **15V VCC source.** Option #2 needs 14.5–15.5V at pin 15. 15V adapter → bridge gives
   ~14.3V: too low. Candidates: (a) 18V adapter → bridge ~17.3V → LDO to 15.0V — but
   17.3V exceeds Daisy VIN max 17V unless the Daisy gets its own pre-regulator; (b) keep the
   9V/15V adapter and add a *quiet* boost (fixed-frequency, well filtered, placed away from
   audio) for the screen only — partly defeats the purpose; (c) accept the module's boost
   with /SHDN control + the §2 ferrite/bulk isolation, and evaluate noise on the breadboard
   first (§11.3 step 4 vs step 1 is exactly this A/B test). Decide from measurement.
7. /CS on D7: hardware NSS vs software-driven GPIO (firmware choice; pin is the same).
8. SSD1322 driver: port `oled_ssd1327` or write fresh; who owns it.

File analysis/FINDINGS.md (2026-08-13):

# Findings Ledger — WavetableController
Rules for entries: see `SOURCE_OF_TRUTH.md` §4. Never delete a finding — refuted ones stay, marked refuted, so we don't re-derive them.

| ID | Pass | Class | Status | Finding | Evidence | Threshold source |
|----|---|---|---|---|---|---|
| F-001 | prior | VIOLATION | confirmed — re-verified Pass 2, refined as F-018 | LED1/LED2 (CLS6B-FKW) drive: 300Ω resistors (R21,R24–R28) to +9V_FILT while other LED terminals go to 3.3V Daisy GPIOs — broken either polarity | Schematic trace, prior session 2026-08-12 | CLS6B-FKW datasheet Vf; Daisy GPIO ratings |
| F-002 | prior→4 | VIOLATION | confirmed (sharpened) | LED1/LED2 (CLS6B-FKW 5050) are the ONLY SMD parts missing from the BOM — boards return from assembly without LEDs. All other BOM absences are through-hole/hand-solder (intentional) | full three-way join, Pass 4 | — |
| F-003 | prior→4 | VIOLATION | confirmed (refined) | BOM S1/S2 = SMD 6×6mm tactile switch (LCSC C2835239) with NO matching board position — the board's 4 tactile switches are all through-hole footprints. Likely intended as TAC_SWITCH_1/2 → footprint-technology mismatch or stale line | full three-way join, Pass 4 | — |
| F-004 | prior | ZERO-MARGIN | confirmed (prior session) | 0.1mm traces board-wide, exactly AT JLCPCB 2-layer 1oz minimum (±20% width tolerance). Carries +3V3_D (~254mm), SD, I2C (~200mm), MIDI UART, USB pair, pot/encoder, LED nets. Recommend 0.2–0.25mm; note 2oz would raise min to 0.16mm | Gerber apertures ADD28/ADD54, ~270 segments/layer | JLCPCB capabilities page, fetched 2026-08-12 |
| F-005 | prior | JUDGMENT | confirmed (prior session) | DRC `min_track_width=0.0` and one `min_clearance=0.0` in .kicad_pro — KiCad won't flag narrow traces. Via/hole minimums ARE set (via 0.5, hole-to-hole 0.25) | .kicad_pro read | — |

| F-006 | 0 | VIOLATION | confirmed | **Source mismatch: `.kicad_pcb` has NO GND pour** — no GND zone exists (the 5 zones present are all net-0 keepouts), no graphics on copper layers, 0 `filled_polygon`; yet B_Cu Gerber contains a 164.1×100.5mm filled region (13,418 vertices — clearly a thermal-relief zone fill). The Gerbers were generated from a different version of the board. In the provided file, GND (63 pads) has only 29 segments × 0.1mm (73mm total), 0 vias → DRC reports 51 missing GND connections | pcb_extract.py + zone/graphics audit + Gerber G36 region measurement + DRC baseline | — (internal consistency) |
| F-007 | 0→3 | VIOLATION | **confirmed (fab truth)** | Encoder click switches dead on the physical boards: /ENCL_CLICK (ENCL1.S1→Daisy pin 11) and /ENCR_CLICK (ENCR1.S1→Daisy pin 29) have no routing in .kicad_pcb AND no copper at any of the 4 pad sites on either layer of the fabbed Gerbers (geometric check). Inputs float. Note: pin 29 is a 3.3V-only pin — no >3V3 pull-up when fixing | Gerber stroke proximity check at pad coords | — |
| F-008 | 0→1 | VIOLATION (marginal) | confirmed | P2 (USB-C) GND pads A1/A12/B1/B12 are 0.194mm from the footprint's own 0.65mm NPTH holes — 6µm below JLCPCB's 0.20mm NPTH-to-copper minimum. Fabbed OK twice (absorbed by tolerance); latent risk in the footprint itself | DRC baseline + drill/pad geometry | JLCPCB caps, fetched 2026-08-13 |
| F-009 | 0 | JUDGMENT | confirmed | U3/U4 fine-pitch pad-to-pad gaps 0.15mm trip the 0.2mm netclass clearance (17 DRC errors). Fab-OK vs JLCPCB 0.1mm min spacing; this is DRC config noise (netclass clearance > footprint geometry), not a fab problem | DRC baseline | JLCPCB caps 2026-08-12 |
| F-010 | 0→6 | JUDGMENT | resolved — deliberate | SW1 (slide switch) sits in a deliberate Edge.Cuts notch; its anchor pads meet the outline (0.0mm vs JLCPCB 0.2mm copper-to-edge). Accepted design deviation, fab-proven twice; occasional edge-copper burrs possible at the notch | Pass 6 outline/pad geometry | JLCPCB caps 2026-08-13 |
| F-011 | 0 | JUDGMENT | superseded by F-024 (all items dispositioned, Pass 3) | ERC errors to triage in Pass 3: USB-C SuperSpeed pins NC (expected — USB2-only), ADC_0/ADC_6 NC, A1-VIN & U4-VDD `power_pin_not_driven` (likely passive/diode-driven false positive), J4 ring NC. Plus 188 lib-symbol/footprint-link warnings (library hygiene) | ERC baseline (207 total) | — |
| F-012 | 0 | — | confirmed | **F-004 corroborated by DRC:** with JLCPCB minimums (0.1mm track/clearance) set, DRC reports zero track-width and zero trace-spacing violations → traces are AT the limit, not below it | DRC on scratchpad copy | JLCPCB caps 2026-08-12 |

| F-013 | align | VIOLATION | confirmed | **Duplicate reference designator R21 in the PCB**: R21 (10R, 0603) at (170.1, 84.8) on /OLED_HOT↔/+3V3_D, AND R21 (300R, 0603) at (154.0, 138.5) on LED1 net↔/+9V_FILT. Schematic has only one R21 (the 300R LED resistor). 79 PCB footprints vs 78 schematic symbols. Breaks BOM/assembly mapping and forward/back annotation | dup-refdes audit of .kicad_pcb vs exported netlist | — |
| F-014 | align | VIOLATION | confirmed | **LED2 wiring disagrees between schematic and PCB** (LED1 matches): PCB has LED2 pin2→Net-(LED2-KB)/R26, pin6→Net-(LED2-KR-Pad6)/R28; schematic has pin2→Net-(LED2-KR-Pad2)/R26, pin6→Net-(LED2-KB)/R28. A pin-swap fix exists in exactly one of the two files — they cannot both be the design intent. Determine which is correct (working boards were built from the Gerbers) and reconcile | net-membership diff, R21–R28 pad-net table | — |
| F-015 | align | JUDGMENT | confirmed (revised) | **Version timeline — revised for provenance**: Gerbers plotted 2026-07-22 (gbrjob CreationDate, embedded metadata = reliable) = fab snapshot of the working boards. The .kicad_* file mtimes (2026-08-12) are likely **transfer times, not edit times** — files were sent piecemeal by Trey (Gerbers+BOM first, then .pro/.sch, then .kicad_pcb last, under protest; user suspects it may be the wrong version). The .kicad_pcb's actual vintage is unknown; it may NOT be Trey's current working file. Content evidence: it matches the LedFix Gerbers 97% (incl. LED2 routing), so it's from near the July fab vintage — but has post- or pre-plot edits and no GND zone. PCB↔Gerber copper is 97% identical (F.Cu 299/308, B.Cu 498/508 exact segment matches); diffs are reroutes near TAC_SWITCH_1 (127,122), TAC_SWITCH_2 (210,122), and the P2/J1/U2 power-entry area — plus the GND pour (F-006). Minor value/lib-prefix noise: C14 PCB Value field holds a footprint name instead of "470UF"; LED1/2 footprint field lacks lib prefix in sch | file mtimes, gbrjob metadata, geometric diff | — |

| F-016 | 1 | VIOLATION (marginal) | confirmed | MK1 pads 1/2 have 0.175mm annular rings (1.0mm pad, 0.65mm drill) — 5µm below JLCPCB's absolute minimum 0.18mm for 2-layer 1oz (recommended ≥0.25). Second tier at exactly 0.200mm (ENCL1/ENCR1 mounting posts, P2 shield) = below recommended, above absolute min. Fabbed OK twice; latent weak-barrel risk | pad/drill geometry from .kicad_pcb + PTH drill file | JLCPCB caps, fetched 2026-08-13 |
| F-017 | 1 | JUDGMENT | confirmed | Gerber drill file has 93 vias; .kicad_pcb has 94 — one-via delta, consistent with F-015 reroute clusters | drill file vs pcb via count | — |

| F-018 | 2 | VIOLATION | confirmed | LED drive refined (supersedes detail of F-001): LEDs permanently reverse-biased (anodes on GPIOs, cathodes to 9V via 300Ω) → can never light; 5.7–9V reverse across dice (typ. LED max ~5V); LED_2_R/LED_1_B/LED_2_B are Daisy pins 24/25/30 = datasheet's **3.3V-only** pins — avalanche would inject into non-5V-tolerant pins | net mapping + Daisy datasheet v1.0.5 Table 1 + Fig 1.8 reference design | Daisy Seed datasheet v1.0.5 (scratchpad copy) |
| F-019 | 2 | JUDGMENT (strong) | confirmed | +3V3_D architecture is the OLED/I2C noise root cause: ONE 100nF (C1, at MIDI opto) for the whole rail; SD power pin 109.5mm away over 0.1mm trace (~0.5Ω), no local cap; 254mm shared trunk. OLED branch's FB4+470µF+100nF+10Ω = symptom fix added during debugging. Fix: local caps at SD + wider trunk | measured cap-to-pin distances, IPC-2221/resistance calc | IPC-2221 computed; loads estimated (flagged) |
| F-020 | 2 | VIOLATION | confirmed | The 10Ω OLED damping resistor (PCB-only duplicate R21) is absent from the schematic — a board-level noise fix that dies silently on any respin from schematic. Ties F-013/F-014 | /OLED_HOT net diff: sch={C14,C17,FB4,J2} vs pcb adds R21(10R) | — |
| F-021 | 2 | — | confirmed | Power checks that PASS (cited): 9V within VIN 4–17V; AGND↔DGND tied (A1.20+A1.40 on GND) per datasheet requirement; SD 47K pullups match Fig 1.6 reference; all rails within IPC-2221 ampacity. NOTE: datasheet publishes no 3v3 output current limit — rail load numbers are estimates | PASS2_POWER.md | Daisy datasheet v1.0.5 |

| F-022 | 3 | JUDGMENT | confirmed | SD card-detect half-wired: /SWA single-pin in schematic (P1.10 floating), SWB tied to GND — card presence unreadable by firmware. Harmless electrically; wire SWA to a GPIO if the feature is wanted | netlist + ERC isolated_pin_label/multiple_net_names | — |
| F-023 | 3 | JUDGMENT | confirmed | 4 dangling GND stubs on B.Cu (0.11–1.85mm) in .kicad_pcb — missing-pour artifact; they terminate into the pour on fabbed boards. Resolves with F-006 | DRC track_dangling details | — |
| F-024 | 3 | JUDGMENT | confirmed | ERC hygiene (supersedes F-011 triage): 13 intentional-NC pins lack no-connect flags (USB-C SS/SBU pins, ADC_0/6, USB_ID); VIN & U4-VDD "not driven" are false positives through D1/FB3 and FB2 (add PWR_FLAGs); J4 ring floating (mono use — revisit in Pass 5). 188 lib warnings = missing local libraries, expected for traveled files. Zero unexplained net diffs after reconciliation | PASS3_CONNECTIVITY.md | — |

| F-025 | 4 | VIOLATION | confirmed | Auto-assembly trap from dup R21 (F-013): BOM's only R21 line = 300Ω; PCB has two R21 positions (300Ω LED + 10Ω OLED damper) → pick-and-place from this PCB places 300Ω at the OLED damper (30× intended series R in the display supply). Physical mis-build on next assembly run | BOM R21 line + pcb dup-refdes audit | — |
| F-026 | 4 | JUDGMENT | confirmed | 18 hand-solder/TH parts absent from SMT BOM (intentional) but no hand-assembly list exists — incl. C14 470µF, part of the OLED noise fix. Recommend second BOM sheet. Values audit: all 58 shared designators BOM↔sch consistent (PASS) | Pass 4 join | — |

| F-027 | 5 | VIOLATION | plausible (pending OLED-module pull-up check) | I2C bus (SCL/SDA ≈ 203/205mm, 3–4 vias each) has NO pull-up resistors anywhere in schematic or BOM — open-drain bus depends on undocumented pull-ups on the OLED module (or 40k STM32 internals). Completes the causal chain with F-019 for the historical I2C/OLED noise. Add explicit 2.2–4.7k pull-ups on respin | 2-node net membership + BOM absence | I2C open-drain requirement (design fundamental) |
| F-028 | 5 | JUDGMENT | confirmed | USB FS pair asymmetry: 127.6 vs 134.8mm, 3 vs 5 vias, 0.1/0.2mm width mix, no impedance control — functionally fine at Full-Speed (proven working); tidy on respin | net geometry extraction | — |
| F-029 | 5 | — | confirmed | MIDI PASSES cited practice: OUT = 10Ω/33Ω (R1/R4) per MIDI 3.3V recommendation; IN = 220Ω (R5) + H11L1 + protection diode. CORRECTION: D1 = MIDI protection diode; the power-entry "Schottky bridge" is D2–D5 (Pass 2 sketch said D1) | netlist trace | MIDI 1.0 3.3V electrical practice |
| F-030 | 5 | JUDGMENT | confirmed | Line-level audio runs long/thin: AUDIO_OUT 285/277mm, AUDIO_IN 213mm, mic return 171mm, all 0.1mm across the board. Works as built (pour beneath, fab truth); keep analog short/edge-routed on respin | net geometry extraction | — |
| F-031 | 5 | JUDGMENT (datasheet-cited) | confirmed | TPA6110A2 supply: 0.1µF close ✓ (C5, 5.5mm) but the datasheet-recommended ≥10µF electrolytic near the amp is ABSENT (3V3_A has only 100nF, 84mm from source). THD/oscillation risk. Mid-rail bypass Eq.6 check PASSES (23ms ≥ 10.3ms) | cap inventory + SLOS314B text (archived) | TPA6110A2 datasheet SLOS314B |

| F-032 | 6 | JUDGMENT | confirmed | No chassis mounting holes — all 28 NPTH are component posts (5×1.2mm per jack, 2.0mm barrel, 0.65mm USB-C). Board must hang from panel hardware (jack/encoder nuts); confirm enclosure plan | NPTH-by-component inventory | — |
| F-033 | 6 | JUDGMENT | confirmed | All 143 silk warnings = front-panel artwork polygons over copper/edge + minor refdes overlaps — cosmetic; fab clips silk on pads. One-time visual check of fab silk preview recommended | silk warning decomposition | — |
| F-034 | 6 | VIOLATION (corroborates F-002) | confirmed | Top paste layer contains exactly the 12 LED pad apertures (LEDs are the only top-side SMD) while LEDs are missing from BOM — the assembly gap is physical: stencil/placement expect parts that never arrive | paste flash counts vs pad inventory | — |
| F-035 | 6 | — | confirmed | Mechanical PASSES: zero courtyard overlaps; mask layers consistent; connectors panel-accessible; drills/edge/hole-spacing covered in Pass 1 | PASS6_MECHANICAL.md | — |

**Alignment verdict (2026-08-12):** the three sources are ~97% the same board. All divergences are enumerated in F-002/003 (BOM), F-006 (pour), F-013/014 (refdes/LED2), F-015 (reroutes). Analysis remains valid under a dual-truth rule: **Gerbers = the physical boards that exist; .kicad_sch/.kicad_pcb = current working intent.** Every further pass must state which truth it's checking against.

**Open threads:** ~~/SWA pads-but-no-copper~~ — resolved in Pass 3: single-pin net in schematic too (card-detect, F-022).

**Not-a-finding register** (deliberate design choices — do not re-flag):
- USB-C is data-only by design; power is 9V barrel via Schottky bridge (decision made after OLED/SSD1309 I2C noise debugging).

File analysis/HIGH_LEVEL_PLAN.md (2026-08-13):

# High-Level Plan — WavetableController PCB Analysis
Governed by `SOURCE_OF_TRUTH.md`. Update the status line of each pass when it completes; do not delete completed passes.

**Status legend:** `NOT STARTED` · `IN PROGRESS` · `COMPLETE` · `BLOCKED`

---

## Pass 0 — Environment & baselines
**Status: COMPLETE** (2026-08-12)
- [x] KiCad **10.0.5** installed to `/Applications/KiCad.app` (brew cask needed sudo → installed from cached DMG instead; `kicad-cli` at `/Applications/KiCad.app/Contents/MacOS/kicad-cli`)
- [x] Framework files created (SOURCE_OF_TRUTH, this plan, FINDINGS ledger)
- [x] Project copied to scratchpad `drc_copy/`; DRC minimums set to JLCPCB values (track 0.1, clearance 0.1) in the copy only
- [x] ERC baseline: 207 violations (17 error-severity) → `drc_copy/erc_report.json`
- [x] DRC baseline: 249 violations + 53 unconnected (51 = GND) → `drc_copy/drc_report.json`
- [x] Parser validated: 0.1mm segment counts match prior Gerber-derived counts (275/282 vs ~270 per layer)
- **Deliverable:** ✅ baselines produced; findings F-006…F-012 logged
- **Headline:** F-006 — the `.kicad_pcb` has no GND pour but the Gerbers do → file-version mismatch; Gerbers are the fab truth for copper

## Pass 1 — Fab constraints
**Status: COMPLETE** (2026-08-13)
- [x] Full extraction: trace widths (0.1/0.2mm only), 93/94 vias all 0.6/0.3mm, complete drill inventory (170 PTH + 28 NPTH), PTH annular rings, hole-to-hole gaps
- [x] JLCPCB capabilities fetched fresh 2026-08-13 (incl. disambiguating via vs component-PTH annular rules)
- [x] PCB↔Gerber cross-check done during alignment audit (97% match; F-015/F-017)
- **Deliverable:** ✅ `PASS1_FAB_CONSTRAINTS.md` — 10-row limit table
- **Result:** 3 marginal violations (F-008 NPTH-to-copper 0.194, F-016 MK1 annular 0.175, F-010 SW1 edge copper 0.0) + the defining zero-margin item (F-004: 3.85m of trace at exactly 0.10mm)

## Pass 2 — Power distribution
**Status: COMPLETE** (2026-08-13)
- [x] Rail topology mapped (9V→Daisy VIN; Daisy 3v3D/3v3A source all peripherals; USB 5V → ESD only)
- [x] IPC-2221 capacity + resistance per rail — ampacity all OK; impedance is the issue
- [x] Decoupling audit — every IC power pin's distance to nearest same-net cap measured
- [x] LED bug re-verified & refined with Daisy datasheet citations (F-018: reverse-biased + 3.3V-only pins 24/25/30)
- [x] Daisy datasheet v1.0.5 fetched & archived; VIN range / AGND tie / SD pullups verified OK
- **Deliverable:** ✅ `PASS2_POWER.md`
- **Result:** F-018 (LED, worse than known), F-019 (3V3_D impedance = OLED/I2C noise root cause), F-020 (PCB-only 10Ω fix not in schematic), F-021 (passing checks)
- **Carried to Pass 5:** TPA6110A2 supply decoupling vs its datasheet

## Pass 3 — Connectivity
**Status: COMPLETE** (2026-08-13)
- [x] Full sch↔pcb netlist diff (done in alignment audit; net-count 93 vs 85 fully reconciled — zero unexplained)
- [x] Encoder clicks verified against fab truth: NO copper at any pad site in Gerbers → F-007 confirmed
- [x] Single-pin (/SWA = half-wired card-detect), dangling (4 GND stubs = pour artifact), unconnected-* (14, intentional) all dispositioned
- [x] All 17 ERC error-severity items dispositioned (10 intentional NC, 3 unused GPIO, 2 PWR_FLAG false positives, 1 jack ring, 1 power flag)
- **Deliverable:** ✅ `PASS3_CONNECTIVITY.md`
- **Result:** F-007 confirmed on fab truth (encoder clicks float); F-022 card-detect unusable; F-023, F-024 hygiene

## Pass 4 — Three-way BOM cross-check
**Status: COMPLETE** (2026-08-13)
- [x] Full three-way join (31 BOM lines ↔ 78 sch refs ↔ 79 pcb footprints), every row dispositioned
- [x] Values audit: all 58 shared designators consistent — zero wrong-part findings
- [x] F-002 sharpened (LEDs = only missing SMD), F-003 refined (S1/S2 = SMD switch vs THT footprints)
- [x] NEW F-025: dup-R21 → 300Ω would be auto-placed at the 10Ω OLED damper position
- **Deliverable:** ✅ `PASS4_BOM.md`

## Pass 5 — Signal-specific
**Status: COMPLETE** (2026-08-13)
- [x] USB FS pair measured (7.2mm/2-via asymmetry — fine at FS; F-028)
- [x] I2C: 203/205mm bus and **ZERO pull-ups in the design** (F-027 — depends on OLED module's onboard pull-ups; pairs with F-019 as the noise causal chain)
- [x] SD: 89–108mm, skew trivial, 47K pullups per reference — PASS
- [x] MIDI: verified against 3.3V MIDI practice — PASS (F-029; D1's true role corrected)
- [x] Audio: TPA6110A2 checked vs SLOS314B — missing recommended ≥10µF bulk (F-031); mid-rail Eq.6 PASS; run-length notes (F-030)
- **Deliverable:** ✅ `PASS5_SIGNALS.md`
- **Carried out:** ask Trey / check OLED module for onboard I2C pull-up value (F-027 confirmation)

## Pass 6 — Mechanical & assembly
**Status: COMPLETE** (2026-08-13)
- [x] SW1 edge copper resolved: deliberate outline notch for slide switch (F-010 → accepted deviation)
- [x] Mounting-hole audit: NO chassis holes; board hangs from panel hardware (F-032)
- [x] Silk warnings decomposed: 143 = panel artwork + minor overlaps, cosmetic (F-033)
- [x] Paste/mask vs Gerbers: top paste = exactly the 12 missing-LED pads (F-034, corroborates F-002); courtyards zero-overlap
- **Deliverable:** ✅ `PASS6_MECHANICAL.md`

## Final — Synthesis
**Status: COMPLETE** (2026-08-13)
- [x] Verification sweep: 33/35 findings confirmed; 2 blocked on Trey (F-014 which-file-is-right, F-027 OLED pull-ups) — explicitly marked, nothing silently open
- [x] Stale statuses closed (F-001 re-verified via Pass 2; F-011 superseded by F-024)
- [x] Ranked report: 4 tiers (working-board defects → next-build landmines → fab margins → robustness) + verified-passes list + 3 questions for Trey
- **Deliverable:** ✅ `FINAL_REPORT.md`

**ALL PASSES COMPLETE.**

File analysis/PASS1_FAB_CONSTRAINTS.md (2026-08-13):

# Pass 1 — Fab Constraints Report
**Date:** 2026-08-13 · **Truth checked:** Gerbers/drills (fab truth) + `.kicad_pcb` for pad geometry · **Thresholds:** JLCPCB capabilities page, fetched 2026-08-13 (2-layer, 1oz)

Every dimension in use vs. JLCPCB's published limit. Classification per SOURCE_OF_TRUTH §4.

| # | Parameter | Board (measured) | JLCPCB limit | Margin | Class |
|---|---|---|---|---|---|
| 1 | Trace width | 0.100mm (557 segs, 3850mm) / 0.200mm (259 segs) | ≥0.10mm | **0.000mm** | **ZERO-MARGIN** (F-004) |
| 2 | Copper spacing | 0.150mm min observed (U3/U4 pad gaps) | ≥0.10mm | 0.050mm | OK |
| 3 | Via diameter / hole | 0.60mm / 0.30mm (93 vias, all identical) | ≥0.25mm dia; dia ≥ hole+0.1mm | 0.35 / 0.20mm | OK |
| 4 | Component PTH annular ring | **0.175mm (MK1.1, MK1.2)**; next: 0.200mm (ENCL1/ENCR1 MP, P2 shield); rest ≥0.25 | abs min 0.18mm; recommended ≥0.25mm | **−0.005mm** | **VIOLATION (marginal)** (F-016) |
| 5 | PTH drill sizes | 0.30, 0.65, 1.00, 1.10, 1.30, 1.85mm (170 holes) | 0.15–6.3mm | ample | OK |
| 6 | NPTH sizes | 0.65 (×2), 1.20 (×25), 2.00mm (×1) | ≥0.50mm | 0.15mm | OK |
| 7 | NPTH-to-copper | **0.194mm** (P2 GND pads A1/A12/B1/B12 to P2's own 0.65mm NPTH) | ≥0.20mm | **−0.006mm** | **VIOLATION (marginal)** (F-008 resolved) |
| 8 | Hole-to-hole gap | 0.500mm min (two vias at 210, −152) | via-via ≥0.2; pad-pad ≥0.45mm | 0.30mm | OK |
| 9 | Copper-to-edge | **0.000mm** (SW1 no-net PTH pads touch Edge.Cuts) | ≥0.20mm | **−0.20mm** | **VIOLATION** (F-010; intent check in Pass 6) |
| 10 | Board thickness | 1.6mm | standard option | — | OK |

## Notes
- **Row 1** is the board's defining fab risk: 3.85 meters of trace at exactly the minimum width, with JLCPCB's stated ±20% width tolerance. Not a spec violation — but zero margin across the majority of the routing, including the +3V3_D power rail. Recommendation (JUDGMENT): widen to 0.2–0.25mm where congestion allows; 2oz copper would raise the minimum to 0.16mm and make current widths illegal.
- **Rows 4, 7, 9** are technically below spec but the boards fabbed successfully twice — JLCPCB's tolerance absorbed them. They are latent risks (a different fab lot, or any fab, may reject or produce weak barrels/exposed edge copper), not observed failures.
- Unused drill-tool definitions (0.4, 0.6, 0.8, 1.5mm at 0 hits) are harmless plot artifacts.
- Gerber has **93** vias; the `.kicad_pcb` has **94** — one-via delta consistent with the F-015 rerouting between versions (F-017).
- Min copper spacing (row 2) is measured from the `.kicad_pcb`; the Gerber pour's clearance to tracks was generated by a zone definition not present in our file — it passed JLCPCB DFM twice, taken as fab-verified.

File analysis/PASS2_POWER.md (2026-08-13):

# Pass 2 — Power Distribution Report
**Date:** 2026-08-13 · **Truth checked:** `.kicad_sch` netlist for topology, `.kicad_pcb` for copper/distances (GND copper deferred to Gerber truth per dual-truth rule) · **Thresholds:** Daisy Seed datasheet v1.0.5 (fetched 2026-08-13, saved in scratchpad), IPC-2221 computed, JLCPCB caps (Pass 1)

## Rail topology (from schematic netlist)
```
9V barrel (J1) → D2–D5 Schottky bridge → FB3 → /+9V_FILT ── A1.39 Daisy VIN  [+ C15 10µF bulk, 67mm away]
   (corrected per Pass 5 F-029: D1 is the MIDI-input protection diode, not the power diode)
                                          └── R21/R24–R28 (300Ω ×6) → LED1/LED2 cathodes  ← THE LED BUG (F-001/F-018)
Daisy A1.38 (3v3 digital out) → /+3V3_D ── SD card P1, MIDI opto U1, 5×47K SD pullups,
                                           FB2 → MAX9814 mic amp, FB4 → /OLED_HOT → J2 OLED
Daisy A1.21 (3v3 analog out)  → /+3V3_A ── U3 TPA6110A2 headphone amp
USB VBUS → /+5V_USB → U2 ESD protector only (data-only USB — by design, not-a-finding)
```

## Verified against datasheet (cited)
| Check | Board | Datasheet | Verdict |
|---|---|---|---|
| VIN range | 9V in | VIN abs max +4…+17V (Table 1) | OK |
| AGND↔DGND tie | A1.20 and A1.40 both on GND | "AGND must be connected to DGND" (Fig 1.1) | OK |
| SD pullups | 5×47K to 3V3_D | "47K pullup resistors necessary, except Pin 7" (Fig 1.6) | OK — matches reference design |
| LED drive | 300Ω to **9V** | Reference: GPIO → 1K → LED → **GND** (Fig 1.8) | **VIOLATION — see F-018** |
| 3v3 rail load capacity | est. ~150mA peak external | **datasheet publishes no 3v3 current limit** | UNVERIFIABLE — load estimate only |

## F-018 — LED drive: worse than previously logged (refines F-001)
LED anodes sit on Daisy GPIOs; cathodes pull to +9V through 300Ω. Consequences, now datasheet-cited:
1. **LEDs can never light** — permanently reverse-biased (GPIO 0–3.3V vs 9V cathode side).
2. **LED dice see 5.7–9V reverse voltage** — typical LED reverse max is ~5V (CLS6B-FKW datasheet to confirm in Pass 4).
3. **Three of the six GPIO pins are the 3.3V-only pins** — LED_2_R=pin 24, LED_1_B=pin 25, LED_2_B=pin 30, exactly on the datasheet's "3.3V tolerant I/O only" list (Table 1 notes). If any reverse-stressed LED die avalanches, it injects current into pins with **no 5V tolerance**. Latent MCU-damage path, not just a dead-LED bug.

## F-019 — +3V3_D distribution architecture (the OLED/I2C noise root cause)
Measured: the entire rail has **one** decoupling cap (C1 100nF, located at the MIDI opto). The SD card's power pin is **109.5mm** from it over 0.1mm trace (≈0.49Ω/100mm ⇒ ~0.5Ω path R), with **no local capacitor**. The rail totals 254mm of 0.1mm trace shared by SD, OLED feed, MIDI opto, and I2C pullups.
- Ampacity is fine (IPC-2221: 0.1mm/1oz = 450mA @ ΔT10°C vs ~150mA est. peak) — **the problem is impedance, not heating**: SD card burst currents (up to ~100mA) create dips/noise on the shared rail.
- The board itself testifies: the OLED branch got a ferrite (FB4) + **470µF** (C14) + 100nF (C17) + a hand-added 10Ω damper (the PCB-only duplicate R21) — symptom treatment added during Trey's noise debugging.
- Recommendation (JUDGMENT): 100nF+10µF at the SD connector, 0.25mm+ rail trunk, and the 470µF band-aid likely becomes unnecessary.

## F-020 — Board-level fix never back-annotated
The 10Ω R21 on /OLED_HOT↔/+3V3_D exists only in the PCB (duplicate refdes, F-013); the schematic's OLED feed is FB4 only. Whoever respins from the schematic loses the noise fix silently.

## Rail copper summary (.kicad_pcb)
| Rail | Copper | IPC-2221 capacity @ΔT10 | Est. load | Path R note |
|---|---|---|---|---|
| /+9V_FILT | 143mm @ 0.2mm | 745mA | Daisy VIN (est. ~100mA) | OK |
| /+3V3_D | 254mm @ 0.1mm + 18mm @ 0.2 | 450mA | ~150mA peak (est.) | ~0.5Ω to SD — F-019 |
| /+3V3_A | 84mm @ 0.2mm | 745mA | headphone amp | supply-cap review → Pass 5 |
| /+5V_USB | 11mm @ 0.2mm | 745mA | ESD chip only | OK |
| GND | 73mm @ 0.1mm (pcb) / **pour (Gerber truth)** | — | — | fine as fabbed; F-006 for the file |

Open item for Pass 5: TPA6110A2 supply decoupling (100nF only) vs its datasheet recommendation — not yet fetched, unverified.

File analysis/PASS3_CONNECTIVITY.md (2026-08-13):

# Pass 3 — Connectivity Report
**Date:** 2026-08-13 · **Truth checked:** both (sch/pcb intent + Gerber fab truth where they diverge)

## Headline: encoder click switches are dead on the physical boards (F-007 → CONFIRMED)
`/ENCL_CLICK` (ENCL1.S1 → Daisy pin 11) and `/ENCR_CLICK` (ENCR1.S1 → Daisy pin 29) are defined in the schematic but have **no routing in the `.kicad_pcb` AND no copper at any of the four pad locations on either layer of the fabbed Gerbers** (geometric check, 0.8mm tolerance). The encoder ground-side pins reach the GND pour, so on the physical boards the click inputs are **floating** — firmware reading them gets undefined levels. This is a fab-truth violation, not a file artifact.
- Note for the future fix: ENCR_CLICK is on Daisy pin 29, one of the datasheet's 3.3V-only pins — fine for a switch-to-GND, but it must never gain a pull-up above 3V3.

## SWA thread resolved (from Pass 0 open threads)
`/SWA` is single-pin **in the schematic too** (P1.10, the microSD card-detect switch A; ERC: "Label connected to only one pin"). Its partner SWB is tied to GND (ERC: name collision, GND wins). So card-detect is half-wired by design: harmless electrically, but **card presence can never be read by firmware**. Classification: JUDGMENT (unused feature), not a defect — unless card-detect was intended.

## Dangling tracks: all four are GND stubs (F-006 artifact)
DRC's 4 `track_dangling` warnings are all short GND stubs on B.Cu (0.11–1.85mm). In the fabbed board these terminate into the GND pour; they only dangle in the pour-less `.kicad_pcb`. No action beyond restoring the pour (F-006).

## ERC error triage — all 17 error-severity items dispositioned
| Items | Disposition |
|---|---|
| P2 TX1±/RX1±/TX2±/RX2±, SBU1/2 not connected (10) | **Intentional** — USB-C 24-pin receptacle used USB2-only (design decision). Cosmetic fix: add no-connect flags |
| A1 ADC_0 (22), ADC_6 (28), USB_ID (1) NC (3) | **Intentional** — unused GPIO. Add no-connect flags |
| A1 VIN "power pin not driven" | **False positive** — driven through D1 Schottky + FB3 (ERC can't see through passives). Add PWR_FLAG |
| U4 VDD "power pin not driven" | **False positive** — driven through FB2 from 3V3_D. Add PWR_FLAG |
| #PWR01 not driven | Missing PWR_FLAG on the 9V input net — cosmetic |
| J4.R not connected | Stereo jack ring left floating (mono use). Acceptable; tie to GND or sleeve if plug-detection/hum matters (Pass 5 audio review) |

The remaining 190 ERC warnings are library-hygiene noise (110 lib_symbol_issues + 78 footprint_link_issues = symbols/footprints not found in local libraries on this machine — expected when files travel without their project libraries; 2 handled above).

## Net-count reconciliation
Schematic 93 pin-bearing nets vs PCB 85: difference fully explained by (a) 14 intentional `unconnected-*` single-pin nets, (b) LED2 net-name skew (F-014), (c) `/SWA` single-pin net. **No unexplained net differences remain.**

## Findings
- **F-007 CONFIRMED (VIOLATION, fab truth):** encoder clicks unrouted on physical boards — floating GPIO inputs.
- **F-022 (JUDGMENT):** SD card-detect half-wired (SWA floating, SWB grounded) — feature unusable as built.
- **F-023 (info):** 4 dangling GND stubs = missing-pour artifact, ties to F-006.
- **F-024 (JUDGMENT):** ERC hygiene — 13 missing no-connect flags, 2 missing PWR_FLAGs; would take ERC errors to zero and make future regressions visible.

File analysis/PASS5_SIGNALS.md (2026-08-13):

# Pass 5 — Signal-Specific Report
**Date:** 2026-08-13 · **Truth checked:** `.kicad_pcb` geometry + schematic networks · **Thresholds:** TPA6110A2 datasheet SLOS314B (fetched, archived in scratchpad), MIDI 1.0 3.3V electrical practice, Daisy datasheet v1.0.5

## F-027 (NEW — the big one): the I2C bus has NO pull-up resistors in this design
`/I2C_SCL` = A1.12 ↔ J2.3 and `/I2C_SDA` = A1.13 ↔ J2.4 — **two-node nets, no resistors, in both schematic and BOM**. I2C is open-drain and cannot work without pull-ups, so the working boards must be relying on pull-ups **on the OLED module itself** (J2 carries a Retroactive 2.42" SSD1306/1309 module; such breakouts usually include ~4.7–10k) or STM32 internal pull-ups (~40k, far too weak for this bus). The bus is **203/205mm long with 3–4 vias per line** — combine an undocumented/uncontrolled pull-up with a 200mm bus sharing the noisy 3V3_D rail (F-019) and you have a complete causal chain for the historical I2C/OLED instability. Action: confirm the module's onboard pull-up value; add explicit 2.2–4.7k pull-ups at the board level on a respin.

## USB (F-028 — JUDGMENT, minor)
MCU-side pair: P = 127.6mm/3 vias, N = 134.8mm/5 vias → 7.2mm and 2-via asymmetry; widths mix 0.1/0.2mm; no impedance control (inherent to 2-layer/1.6mm). At Full-Speed (12Mbps, ~7mm ≈ 45ps vs multi-ns edges) this is functionally fine — and field-proven. Tidy on respin, not a defect. USB routes through U2 (USBLC6-2P6 ESD) correctly.

## MIDI (F-029 — PASS, cited)
- **MIDI OUT (J3):** USART1_TX → R1 10Ω → Tip; +3V3_D → R4 33Ω → Ring — exactly the MIDI 3.3V electrical recommendation (10Ω data / 33Ω source).
- **MIDI IN (J6):** Ring/Tip → R2/R3 (0Ω) → H11L1 opto (the classic MIDI opto) with 220Ω current limit (R5) and reverse-protection diode — textbook.
- **Refdes clarification recorded:** D1 is the MIDI-input protection diode, NOT the power diode; the barrel input's "Schottky bridge" is D2–D5. (Corrects the Pass 2 topology sketch's "D1 Schottky" label.)

## SD interface (PASS)
Runs 89–108mm, max skew ~19mm (~130ps — irrelevant at SDIO 25–50MHz). 47K pull-ups per Daisy reference design (verified Pass 2). Width mix 0.1/0.2mm noted; harmless.

## Audio path
- **F-031 (JUDGMENT, datasheet-cited): headphone amp bulk cap missing.** TPA6110A2 SLOS314B: 0.1µF close to VDD ✓ (C5 at 5.5mm) **plus** "aluminum electrolytic capacitor of 10µF or greater placed near the power amplifier is recommended" — absent; 3V3_A has only the 100nF, fed over 84mm from the Daisy. THD/oscillation risk per datasheet, especially with long output leads.
- **Mid-rail bypass check (PASS, computed per datasheet Eq. 6):** C(B)·230k = 100nF·230k = 23ms ≥ Ci·Ri = 470nF·22k = 10.3ms ✓.
- Output coupling 100µF (C6/C7) + 10k bleed resistors (R22/R23) to GND — good practice ✓.
- **F-030 (JUDGMENT):** line-level audio runs are long and thin: AUDIO_OUT_L/R 285/277mm, AUDIO_IN_L 213mm, mic return 171mm — all 0.1mm, crossing the board over the (Gerber-truth) ground pour. Works as built; on a respin keep analog shorter/edge-routed and away from SD/USB corridors.
- J4 (audio in) ring floating — mono-source assumption, acceptable (carried from F-024).

## Findings ledger updates
F-027 (I2C pull-ups — VIOLATION-plausible pending module check), F-028 (USB tidy-up), F-029 (MIDI PASS + D1 role corrected), F-030 (audio run lengths), F-031 (TPA6110 bulk cap, datasheet-cited).

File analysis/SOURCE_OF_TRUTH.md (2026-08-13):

# Source of Truth — PCB Analysis Methodology
**Project:** WavetableController (Electrosmith Daisy Seed wavetable synth controller, 2-layer 165×102mm, KiCad 9)
**Established:** 2026-08-12
**Status:** Governing document. Every analysis pass must follow these rules. Re-read before starting each pass.

---

## 1. Ground truth hierarchy

| Rank | Source | Role |
|---|---|---|
| 1 | `WavetableController.kicad_pcb` | Authoritative layout (s-expression, fully parseable) |
| 1 | `WavetableController.kicad_sch` | Authoritative connectivity intent |
| 2 | `Manifold_Gerb_LedFix/*.gbr, *.drl` | What was actually sent to fab — cross-check against #1 |
| 3 | `ManifoldRe_BOM_NEW - Excel Format.xls` | Procurement — third independent source |

**Discrepancies between sources are themselves red flags** (e.g., BOM designators that don't exist in the schematic).

**Dual-truth rule (established 2026-08-12, see FINDINGS F-006/F-013/F-014/F-015):** the sources are ~97% aligned but NOT identical. Gerbers (plotted 2026-07-22) describe the physical boards that exist and work; the .kicad_sch/.kicad_pcb (saved 2026-08-12) are the current working intent, which diverges at: GND pour (Gerber-only), LED2 wiring (sch vs pcb disagree), duplicate R21 (pcb), reroutes near TAC_SWITCH_1/2 and the power entry. Every pass must state which truth it checks against: fab-related passes (1, 6) → Gerbers; intent-related passes (2, 3, 4, 5) → KiCad files, with Gerber cross-check where they diverge.

## 2. Core rules — how every finding is produced

1. **Every red flag = measured fact + cited threshold.** The measurement comes from a script; the threshold comes from a fetched authoritative source, never from model memory.
2. **Extract numbers with scripts, never by "reading and noticing."** Write parsers that emit complete tables (all trace widths, all clearances below X, full footprint↔BOM mapping). Judgment operates only on those tables. A script over the whole file can't fatigue halfway through.
3. **Don't hand-roll what a real tool does better.** Use `kicad-cli` ERC/DRC as the completeness anchor. Custom scripts fill only the gaps DRC doesn't cover (BOM cross-checks, current capacity, fab-specific rules).
4. **Never modify the design files.** DRC runs that need adjusted settings (e.g., the zeroed min_track_width) use a *copy* of the project in the scratchpad.
5. **Validate parsers before trusting them.** Every custom extraction gets a known-answer check (e.g., prior session validated Gerber-to-net matching 6/6 on LED nets before use).

## 3. Threshold sources (fetch live, per claim class)

| Claim class | Authoritative source |
|---|---|
| Fab rules (min trace/space/via/annular ring) | JLCPCB capabilities page — fetched 2026-08-12: 2-layer 1oz min 0.10mm/4mil, ±20% width tolerance; 2oz raises min to 0.16mm |
| Trace current capacity | IPC-2221 external-trace formula, computed per trace |
| Part behavior (pinouts, Vf, ratings) | The actual datasheet (Daisy Seed, CLS6B-FKW LED, etc.) |
| Interface rules | The relevant spec (USB 2.0 FS pair, I2C bus capacitance) |

## 4. Finding classification

Every finding is labeled exactly one of:

- **VIOLATION** — measured fact breaks a cited rule
- **ZERO-MARGIN** — at a limit but not past it (e.g., 0.1mm traces exactly at JLCPCB's minimum)
- **JUDGMENT** — recommendation; explicitly opinion, no rule citation claimed

And carries a status: `plausible` → `confirmed` / `refuted`. Nothing is reported as real until independently verified. Findings live in `analysis/FINDINGS.md` and never silently evaporate between passes.

## 5. Lessons already paid for (do not repeat)

1. **The 0.1mm trace error:** first flagged as *below* JLCPCB minimum from memory; fetching the actual capabilities page showed it's exactly *at* the 0.10mm minimum — a zero-margin finding, not a violation. → Rule 1 exists because of this.
2. **The "all DRC minimums are zero" overstatement:** a closer read showed only `min_track_width` and one clearance are zeroed; via/hole minimums are set. → Partial reads produce overstatements; run complete extractions.

## 6. Process

- One pass per domain (see `HIGH_LEVEL_PLAN.md`), reviewed between passes.
- After each pass: update FINDINGS.md, mark the pass complete in HIGH_LEVEL_PLAN.md, re-read this document before the next pass.
- Verification of `plausible` findings is a distinct step, done with independent method/source from the original detection.

## 7. Known project context (from prior sessions, 2026-08-12)

- Board is on its 2nd JLCPCB proto round; **boards physically work**.
- USB-C is data-only by design (9V barrel via Schottky bridge) — a deliberate choice after OLED/SSD1309 I2C noise debugging. Don't flag as an oversight.
- Known prior findings to re-verify against the now-available `.kicad_pcb`: LED 9V-drive bug (LED1/LED2 resistors to +9V_FILT vs 3.3V GPIOs), LEDs missing from BOM, phantom BOM designators S1/S2, 0.1mm traces on +3V3_D (~254mm run), SD, I2C, USB, MIDI, pot/encoder, LED nets.

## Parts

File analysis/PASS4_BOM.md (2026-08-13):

# Pass 4 — Three-Way BOM Cross-Check
**Date:** 2026-08-13 · **Sources:** `ManifoldRe_BOM_NEW - Excel Format.xls` (31 lines, JLCPCB format: Comment/Designator/Footprint/LCSC#) ↔ schematic (78 refs) ↔ `.kicad_pcb` (79 footprints incl. dup R21)

## Verdict summary
- **Values: 100% consistent.** Every shared designator's BOM description matches the schematic value (all 58 checked: resistor values, cap values/dielectrics, ICs, connectors). No wrong-part findings.
- **The only SMD parts missing from the BOM are LED1/LED2** (F-002 sharpened — see below).
- **Every through-hole part is absent from the BOM** — consistent with a JLCPCB *SMT assembly* BOM where TH parts are hand-soldered. Intentional, but see F-026.
- **Two assembly landmines found:** S1/S2 (F-003 refined) and the duplicate-R21 placement trap (F-025, new).

## F-002 (sharpened): LED1/LED2 are the ONLY missing SMD parts
CLS6B-FKW RGB 5050 LEDs, top side. Boards return from assembly without LEDs. Combined with F-018 (they're wired to never light), the LED subsystem is doubly broken: not placed, and unable to work if placed.

## F-003 (refined): S1/S2 are a footprint-technology mismatch, not just phantoms
BOM S1/S2 = **SMD**-4P 6×6mm tactile switch (LCSC C2835239). The board's four tactile switches (TAC_SWITCH_1/2, TAC_SHIFT_L1/R1) are all **through-hole** footprints. So S1/S2 most plausibly *intend* TAC_SWITCH_1/2 — but as an SMD part that cannot mount on the THT footprints. Either a stale line from another revision or a part-selection/footprint divergence. Assembly house behavior: two BOM lines with no matching placement positions → flagged or silently skipped.

## F-025 (NEW — VIOLATION): the duplicate R21 is an auto-assembly trap
The BOM's only R21 line is **300Ω** (grouped with R24–R28, the LED resistors). The PCB contains **two** R21 positions: the 300Ω LED resistor *and* the 10Ω OLED damper (F-013/F-020). Any pick-and-place file exported from this PCB has two "R21" placements resolving to the single 300Ω BOM line → **a 300Ω resistor gets placed at the OLED damper position**, starving the OLED feed (30× the intended resistance in series with the display supply). This converts the refdes duplication from a bookkeeping bug into a physical mis-build on the next assembly run.

## F-026 (JUDGMENT): hand-assembly parts have no list
18 parts are TH/hand-soldered and appear on no BOM: A1 Daisy Seed, ENCL1/ENCR1 encoders, J1–J7 (OLED, MIDI ×2, audio ×3, phones... J1 barrel *is* in the SMT BOM), SW1, MK1 mic, C14 **470µF** (the OLED noise-fix bulk cap), TAC_×4. Risk: the noise-fix cap and other hand parts rely on memory. Recommend a second "hand assembly" BOM sheet.

## Housekeeping
- BOM D1 (C385198) differs from D2–D5 (C727114) — both Schottky, D1 is the power-entry diode: legitimate, not a mismatch.
- BOM encoding artifacts (`¬±`, `‚ÑÉ`, `Œ©` = mojibake for ±, ℃, Ω) — cosmetic only; LCSC part numbers are the authoritative column and are intact.
- BOM filename says "ManifoldRe", sheet says "WaveControllerBOM_NEW" — same project, naming drift only.

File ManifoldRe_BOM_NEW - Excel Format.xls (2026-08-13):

Comment | Designator | Footprint | JLCPCB Part #
1 Independent 1A 20V 40uA@15V 540mV@1A 5A SOD-323 Schottky Diodes ROHS | D1 | SOD-323 | C385198
-55_~+150_ 1A 1mA 20V 750mV@3A 9A Independent SOD-323 Schottky Diodes ROHS | D2,D3,D4,D5 | SOD-323 | C727114
-55‚ÑÉ~+155‚ÑÉ 0Œ© 100mW 75V Thick Film Resistor ¬±1% 0603 Chip Resistor - Surface Mount ROHS | R2,R3 | 603 | C21189
-55℃~+155℃ 100mW 220Ω 75V Thick Film Resistor ±100ppm/℃ ±5% 0603 Chip Resistor - Surface Mount ROHS | R5 | 603 | C1226
-40‚ÑÉ~+85‚ÑÉ 0.4V 1 1.2V 1.6mA 1Mbit/s 250mW 30mA 3V~15V 4.17kV 4us 4us 50mA 6V DC SOP-6-2.54mm Logic Output Optoisolators ROHS | U1 | SOP-6-2.54mm | C20082
-55‚ÑÉ~+155‚ÑÉ 100mW 270Œ© 75V Thick Film Resistor ¬±1% ¬±100ppm/‚ÑÉ 0603 Chip Resistor - Surface Mount ROHS | R6 | 603 | C22966
100nF 25V X7R ¬±10% 0603 Multilayer Ceramic Capacitors MLCC - SMD/SMT ROHS | C1, C4, C5, C8, C11,C16, C17 | 603 | C1590
-25‚ÑÉ~+85‚ÑÉ 1.68mm Connector and Ejector MicroSD Card (TF Card) No Push-Push SMD SD Card / Memory Card Connector ROHS | P1 | SMD | C114218
-55‚ÑÉ~+155‚ÑÉ 100mW 47kŒ© 75V Thick Film Resistor ¬±100ppm/‚ÑÉ ¬±5% 0603 Chip Resistor - Surface Mount ROHS | R7,R8,R9,R10,R11 | 603 | C25600
-40‚ÑÉ~+85‚ÑÉ 0.6% 1.5mA 100dB 150mWx2@16Œ© 2-Channel 2.5V~5.5V 76dB Automatic mute/no-noise switch„ÄÅESD protection Class AB MSOP-8-EP Audio Amplifiers ROHS | U3 | MSOP-8-EP | C130212
-55‚ÑÉ~+155‚ÑÉ 100mW 22kŒ© 75V Thick Film Resistor ¬±100ppm/‚ÑÉ ¬±5% 0603 Chip Resistor - Surface Mount ROHS | R12, R13 | 603 | C23344
25V 470nF X7R ¬±10% 0603 Multilayer Ceramic Capacitors MLCC - SMD/SMT ROHS | C2, C3, C10 | 603 | C1623
-55‚ÑÉ~+155‚ÑÉ 100mW 33kŒ© 75V Thick Film Resistor ¬±1% ¬±100ppm/‚ÑÉ 0603 Chip Resistor - Surface Mount ROHS | R14, R15 | 603 | C4216
-55‚ÑÉ~+105‚ÑÉ 100uF 2000hrs@105‚ÑÉ 35V 6.3mm 7.7mm ¬±20% SMD,D6.3xL7.7mm Aluminum Electrolytic Capacitors - SMD ROHS | C6, C7 | SMD,D6.3xL7.7mm | C3339
SOT-666 ESD and Surge Protection (TVS/ESD) ROHS | U2 | SOT-666 | C53059594
-40‚ÑÉ~+85‚ÑÉ 1 10,000 Cycles 16P 30V 3A Black Female Surface Mount, Right Angle Type-C SMD USB Connectors ROHS | P2 | SMD | C393939
-55℃~+155℃ 100mW 5.1kΩ 75V Thick Film Resistor ±1% ±100ppm/℃ 0603 Chip Resistor - Surface Mount ROHS | R16, R17 | 603 | C23186
-40‚ÑÉ~+85‚ÑÉ 0.04% 1-Channel 2.7V~5.5V 50dB 61dB Class AB Enable/disable function„ÄÅDigital programmable gain TDFN-14-EP(3x3) Audio Amplifiers ROHS | U4 | TDFN-14-EP(3x3) | C41714
-55℃~+125℃ 1 200mA 450mΩ 600Ω@100MHz ±25% 0603 Ferrite Beads ROHS | FB1 ,FB2,FB3,FB4 | 603 | C1002
10V 2.2uF X5R ¬±10% 0603 Multilayer Ceramic Capacitors MLCC - SMD/SMT ROHS | C9, C13 | 603 | C1607
-55℃~+155℃ 100kΩ 100mW 75V Thick Film Resistor ±1% ±100ppm/℃ 0603 Chip Resistor - Surface Mount ROHS | R18 | 603 | C14675
-55‚ÑÉ~+155‚ÑÉ 100mW 150kŒ© 75V Thick Film Resistor ¬±1% ¬±100ppm/‚ÑÉ 0603 Chip Resistor - Surface Mount ROHS | R19 | 603 | C22807
-55‚ÑÉ~+155‚ÑÉ 100mW 2.2kŒ© 75V Thick Film Resistor ¬±1% ¬±100ppm/‚ÑÉ 0603 Chip Resistor - Surface Mount ROHS | R20 | 603 | C4190
10V 4.7uF X5R ¬±10% 0603 Multilayer Ceramic Capacitors MLCC - SMD/SMT ROHS | C12 | 603 | C1705
-35_~+75_ 12V 2mm 3A 6.4mm DC Power Jack Surface Mount, Right Angle SMD DC Power Connectors ROHS | J1 | SMD | C114916
-40_~+105_ 100V 10uF 2000hrs@105_ 38mA@120Hz 6.3mm 7.7mm ±20% SMD,D6.3xL7.7mm Aluminum Electrolytic Capacitors - SMD ROHS | C15 | SMD,D6.3xL7.7mm | C72482
-30_~+80_ 100,000 cycles 12V 2.6N 5.5mm 50mA 6mm 6mm Black Gull Wing Round Button SPST Surface Mount,Vertical Without Bracket SMD-4P,6x6mm Tactile Switches ROHS | S1, S2 | SMD-4P,6x6mm | C2835239
-55_~+155_ 100mW 10kΩ 75V Thick Film Resistor ±100ppm/_ ±5% 0603 Chip Resistor - Surface Mount ROHS | R22, R23 | 603 | C22369937
-55℃~+155℃ 100mW 10Ω 75V Thick Film Resistor ±1% ±400ppm/℃ 0603 Chip Resistor - Surface Mount ROHS | R1 | 603 | C22859
-55℃~+155℃ 100mW 33Ω 75V Thick Film Resistor ±1% ±100ppm/℃ 0603 Chip Resistor - Surface Mount ROHS | R4 | 603 | C23140
-55℃~+155℃ 100mW 300Ω 75V Thick Film Resistor ±1% ±100ppm/℃ 0603 Chip Resistor - Surface Mount ROHS | R21, R24,R25,R26,R27,R28 | 603 | C23025

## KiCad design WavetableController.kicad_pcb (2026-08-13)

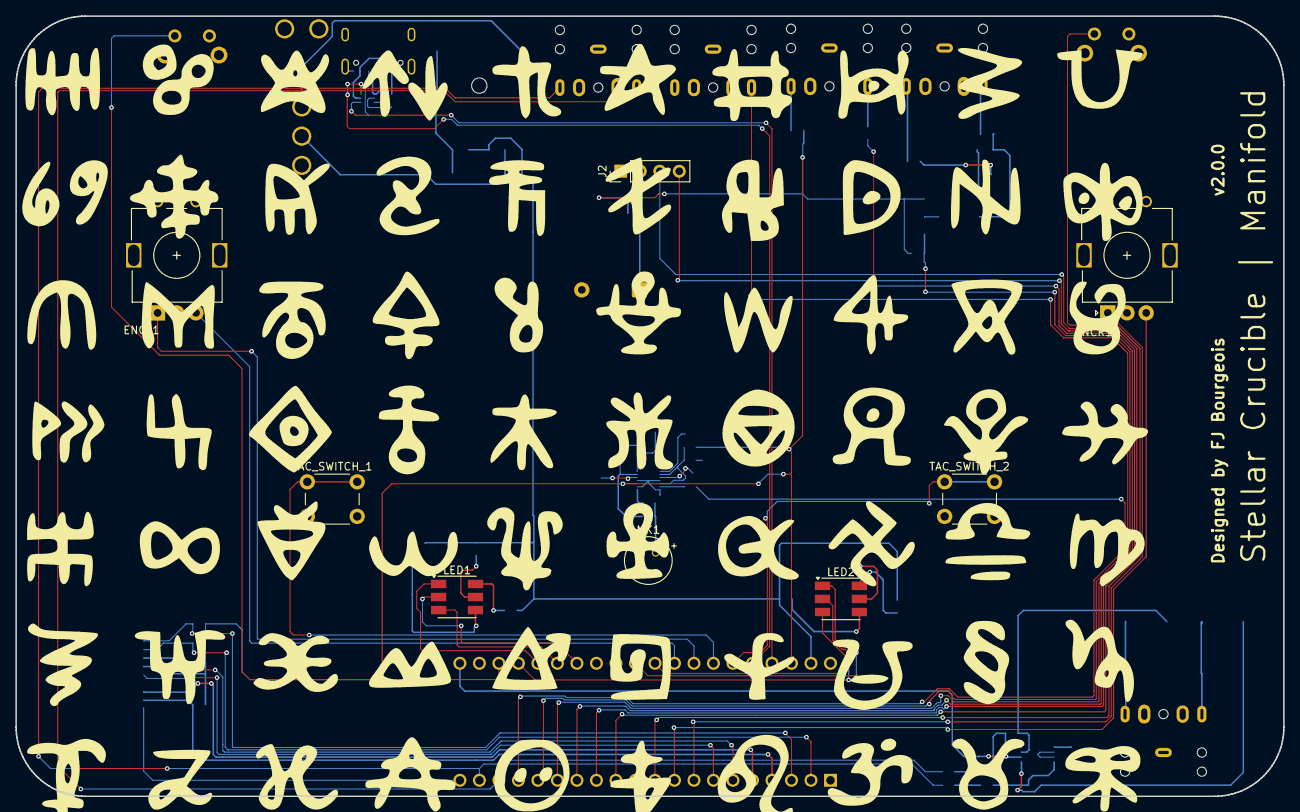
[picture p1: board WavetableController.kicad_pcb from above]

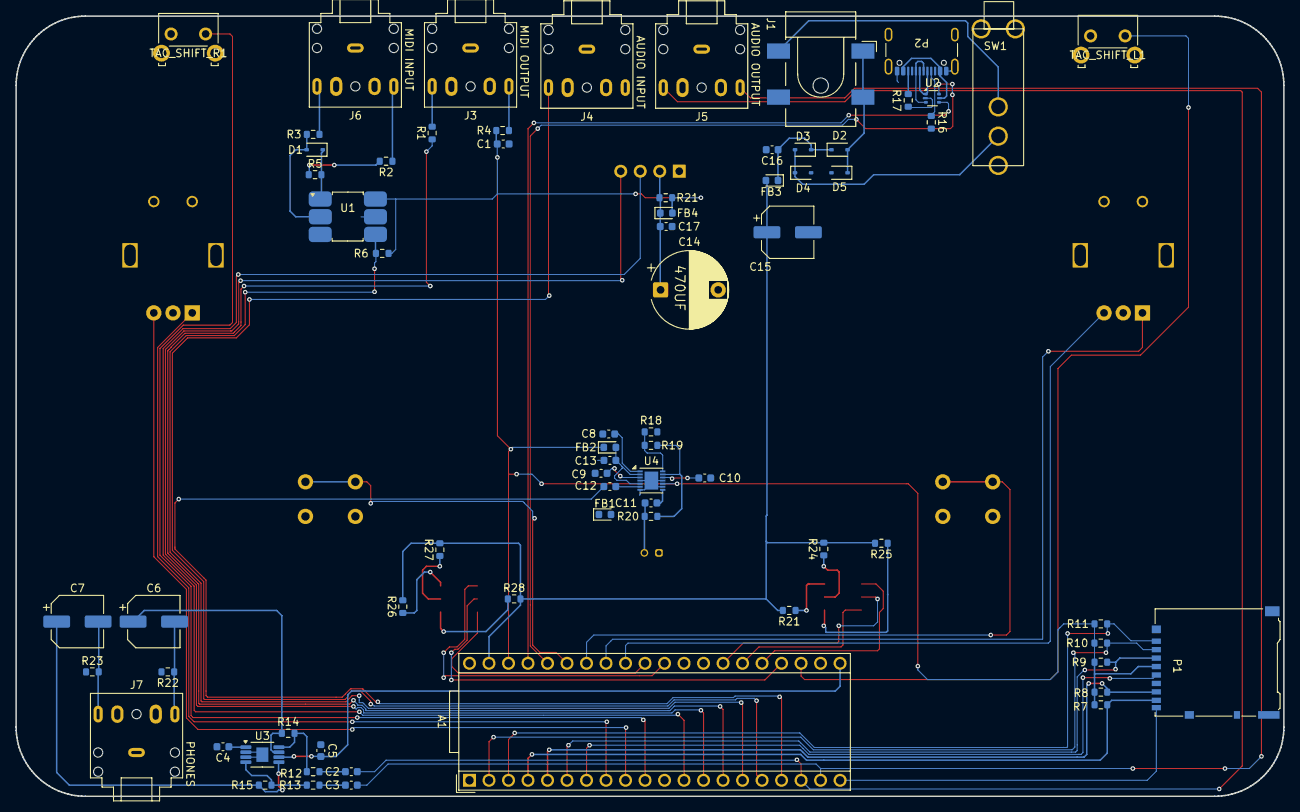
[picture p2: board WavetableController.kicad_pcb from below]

Board: 2 copper layers, 165.1 x 101.6 mm, 79 parts (71 on the bottom side), 77 nets.

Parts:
A1: Electrosmith_Daisy_Seed_Rev4; Electrosmith_Daisy_Seed_Cuz
C1, C4, C5, C8, C11, C16, C17: 100NF; C_0603_1608Metric
C2, C3, C10: 470NF; C_0603_1608Metric
C6, C7: 100UF; CP_Elec_6.3x7.7
C9, C13: 2.2UF; C_0603_1608Metric
C12: 4.7UF; C_0603_1608Metric
C14: CP_Radial_D10.0mm_P7.50mm
C15: 10UF; CP_Elec_6.3x7.7
D1, D2, D3, D4, D5: D_Schottky; D_SOD-323
ENCL1: RotaryEncoder_Switch; RotaryEncoder_Alps_Vertical_H20mm
ENCR1: RotaryEncoder_Switch; RotaryEncoder_Alps_Vertical_H20mm
FB1, FB2, FB3, FB4: FerriteBead; D_0603_1608Metric
J1: Barrel_Jack; Retroactive_SMDBarrelJack_CLIFF
J2: SSD1306 OLED; Retroactive_2.42_OLED_I2C
J3: MIDI OUTPUT; Jack_3.5mm_CUI_RetroactiveCustom
J4: AUDIO INPUT; Jack_3.5mm_CUI_RetroactiveCustom
J5: AUDIO OUTPUT; Jack_3.5mm_CUI_RetroactiveCustom
J6: MIDI INPUT; Jack_3.5mm_CUI_RetroactiveCustom
J7: PHONES; Jack_3.5mm_CUI_RetroactiveCustom
LED1, LED2: CLS6B-FKW; LED_RGB_5050-6
MK1: Microphone_Condenser; POM-2244P-C3310-2-R
P1: Micro_SD_Card_Det2; microSD_HC_Hirose_DM3AT-SF-PEJM5
P2: USB_C31-S-RA-CS2-SMT-BK-T/R; USB_C_Receptacle_GCT_USB4105-xx-A_16P_TopMnt_Horizontal
R1, R21: 10R; R_0603_1608Metric
R2, R3: 0R; R_0603_1608Metric
R4: 33R; R_0603_1608Metric
R5: 220R; R_0603_1608Metric
R6: 270R; R_0603_1608Metric
R7, R8, R9, R10, R11: 47K; R_0603_1608Metric
R12, R13: 22K; R_0603_1608Metric
R14, R15: 33K; R_0603_1608Metric
R16, R17: 5K1; R_0603_1608Metric
R18: 100K; R_0603_1608Metric
R19: 150K; R_0603_1608Metric
R20: 2K2; R_0603_1608Metric
R21#2, R24, R25, R26, R27, R28: 300R; R_0603_1608Metric
R22, R23: 10k; R_0603_1608Metric
SW1: Power ON/OFF; DigiKey_1101A4VQEA_SPDT_Vertical_SlideSwitch
TAC_SHIFT_L1: SW_Push; Retroactive_90DegSW_Tactile
TAC_SHIFT_R1: SW_Push; Retroactive_90DegSW_Tactile
TAC_SWITCH_1, TAC_SWITCH_2: SW_MEC_5E; Retroactive_THT_TACTSW_6mm_H9.5mm
U1: H11L1; SOP-6_3.8x4.1mm_P2.54mm(RetroactiveCustom)
U2: USBLC6-2P6; SOT-666
U3: TPA6110A2DGN; HVSSOP-8-1EP_3x3mm_P0.65mm_EP1.57x1.89mm
U4: MAX9814; DFN-14-1EP_3x3mm_P0.4mm_EP1.78x2.35mm

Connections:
/+3V3_A: A1.21 (3V3_A), C5.1, U3.6 (VDD)
/+3V3_D: A1.38 (3V3_D), C1.1, FB2.1, FB4.2, P1.4 (VDD), R4.1, R6.2, R7.1, R8.1, R9.1, R10.1, R11.1, R21.2, U1.6, U4.10 (GAIN)
/+5V_USB: P2.A4 (VBUS), P2.A9 (VBUS), P2.B4 (VBUS), P2.B9 (VBUS), U2.5 (VBUS)
/+9V_FILT: A1.39 (VIN), C15.1, FB3.2, R21#2.2, R24.2, R25.2, R26.2, R27.2, R28.2
/ENCL_A: A1.33 (SAI2_SD_A), ENCL1.A
/ENCL_B: A1.32 (SAI2_SD_B), ENCL1.B
/ENCL_CLICK: A1.11 (SPI1_PICO), ENCL1.1
/ENCR_A: A1.8 (SPI1_CS), ENCR1.A
/ENCR_B: A1.9 (SPI1_SCK), ENCR1.B
/ENCR_CLICK: A1.29 (DAC_OUT2), ENCR1.1
/I2C_SCL: A1.12 (I2C1_SCL), J2.3
/I2C_SDA: A1.13 (I2C1_SDA), J2.4
/LED_1_B: A1.25 (ADC_3), LED1.1 (AR)
/LED_1_G: A1.26 (ADC_4), LED1.5 (AB)
/LED_1_R: A1.27 (ADC_5), LED1.3 (AG)
/LED_2_B: A1.30 (DAC_OUT1), LED2.1 (AB)
/LED_2_G: A1.31 (SAI2_MCLK), LED2.5 (AG)
/LED_2_R: A1.24 (ADC_2), LED2.3 (AR)
/MIC_HOT: C11.1, MK1.2 (+), R20.1
/MIDI_IN_RING: J6.R, R2.1
/MIDI_IN_TIP: J6.T, R3.1
/OLED_HOT: C14.1, C17.1, FB4.1, J2.2, R21.1
/SD_CK: A1.7 (SD_CLK), P1.5 (CLK)
/SD_CMD: A1.6 (SD_CMD), P1.3 (CMD), R9.2
/SD_D0: A1.5 (SD_DATA_0), P1.7 (DAT0), R8.2
/SD_D1: A1.4 (SD_DATA_1), P1.8 (DAT1), R7.2
/SD_D2: A1.3 (SD_DATA_2), P1.1 (DAT2), R11.2
/SD_D3: A1.2 (SD_DATA_3), P1.2 (DAT3/CD), R10.2
/TAC_SHIFT_L: A1.23 (ADC_1), TAC_SHIFT_L1.2
/TAC_SHIFT_R: A1.10 (SPI1_POCI), TAC_SHIFT_R1.2
/TAC_SWITCH_1: A1.34 (SAI2_FS), TAC_SWITCH_1.1, TAC_SWITCH_1.4 (A)
/TAC_SWITCH_2: A1.35 (SAI2_SCK), TAC_SWITCH_2.1, TAC_SWITCH_2.4 (A)
/USART1_RX: A1.15 (USART1_RX), R6.1, U1.4
/USART1_TX: A1.14 (USART1_TX), R1.1
/USB_IN_MCU_N: A1.36 (USB_D_-), U2.6 (I/O1)
/USB_IN_MCU_P: A1.37 (USB_D_+), U2.4 (I/O2)
/USB_IN_N: P2.A7 (D-), P2.B7 (D-), U2.1 (I/O1)
/USB_IN_P: P2.A6 (D+), P2.B6 (D+), U2.3 (I/O2)
AUDIO_IN_L: A1.16 (AUDIO_IN_1), J4.T
AUDIO_MIC_IN_R: A1.17 (AUDIO_IN_2), C12.2
AUDIO_OUT_L: A1.18 (AUDIO_OUT_1), C2.1, J5.T
AUDIO_OUT_R: A1.19 (AUDIO_OUT_2), C3.1, J5.R
GND: A1.20 (AGND), A1.40 (DGND), C1.2, C4.2, C5.2, C8.1, C9.1, C10.1, C13.1, C14.2, C15.2, C16.2, C17.2, D4.2 (A), D5.2 (A), ENCL1.2, ENCL1.C, ENCR1.2, ENCR1.C, FB1.1, FB1.2, J2.1, J3.S, J4.S, J5.S, J6.S, J7.S, MK1.1 (-), P1.6 (VSS), P1.9 (DET_B), P1.11 (SHIELD), P2.A1 (GND), P2.A12 (GND), P2.B1 (GND), P2.B12 (GND), P2.S1 (SHIELD), R16.2, R17.2, R18.1, R22.2, R23.1, TAC_SHIFT_L1.1, TAC_SHIFT_R1.1, TAC_SWITCH_1.2, TAC_SWITCH_1.3 (K), TAC_SWITCH_2.2, TAC_SWITCH_2.3 (K), U1.5, U2.2 (GND), U3.2 (GND), U3.3 (SHDN), U3.9 (GND), U4.4 (GND), U4.7 (GND), U4.9 (A/R), U4.11 (GND), U4.15 (GND)
HEADPHONE_OUT_L: C6.2, J7.T, R22.1
HEADPHONE_OUT_R: C7.2, J7.R, R23.2
unnamed: C2.2, R12.1
unnamed: C3.2, R13.1
unnamed: D1.2 (A), R3.2, U1.2
unnamed: D1.1 (K), R5.2, U1.1
unnamed: D2.2 (A), D5.1 (K), J1.1
unnamed: C16.1, D2.1 (K), D3.1 (K), FB3.1
unnamed: D3.2 (A), D4.1 (K), SW1.2 (B)
unnamed: J3.R, R4.2
unnamed: J3.T, R1.2
unnamed: LED1.6 (KB), R25.1
unnamed: LED1.2 (KR), R21#2.1
unnamed: LED1.4 (KR), R24.1
unnamed: LED2.2 (KB), R26.1
unnamed: LED2.4 (KR), R27.1
unnamed: LED2.6 (KR), R28.1
unnamed: P2.A5 (CC1), R16.1
unnamed: P2.B5 (CC2), R17.1
unnamed: R2.2, R5.1
unnamed: J1.2, SW1.1 (A)
unnamed: C4.1, U3.1 (BYPASS)
unnamed: R12.2, R14.1, U3.8 (IN1-)
unnamed: R13.2, R15.1, U3.4 (IN2-)
unnamed: C6.1, R14.2, U3.7 (VO1)
unnamed: C7.1, R15.2, U3.5 (VO2)
unnamed: C10.2, U4.12 (BIAS)
unnamed: C9.2, U4.3 (CG)
unnamed: C8.2, U4.1 (CT)
unnamed: R19.1, R20.2, U4.13 (MICBIAS)
unnamed: C11.2, U4.8 (MICIN)
unnamed: C12.1, U4.6 (MICOUT)
unnamed: R18.2, R19.2, U4.14 (TH)
unnamed: C13.2, FB2.2, U4.2 (~SHDN), U4.5 (VDD)

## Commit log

2026-08-13 Initial commit: WavetableController PCB analysis and design files
    [ManifoldRe_BOM_NEW - Excel Format.xls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]
2026-09-15 Add KiCad 9 headless setup and smoke-test scripts
    kicad-cli 9.0.9 was installed but ERC/DRC emitted ~190 'library not found'
    warnings because the stock symbol/footprint packages and user lib tables
    were missing. tools/kicad_env_setup.sh installs kicad-symbols and
    kicad-footprints and seeds ~/.config/kicad/9.0/{sym,fp}-lib-table;
    tools/kicad_check.sh runs ERC, DRC, netlist, Gerber, SVG and PDF exports
    plus a pcbnew Python API load as a smoke test. README tooling notes
    updated for the Linux environment; kicad_out/ is git-ignored.
    Claude-Session: https://claude.ai/code/session_017Ze9fV48htnNQJJSQtp24X
2026-09-15 Add SessionStart hook that runs the KiCad 9 environment setup
    .claude/hooks/session-start.sh calls tools/kicad_env_setup.sh in Claude
    Code on the web sessions so kicad-cli, pcbnew and the stock libraries are
    ready before the session starts. Registered in .claude/settings.json.
    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
2026-09-15 Add Freerouting autorouter to the KiCad environment setup
    tools/kicad_env_setup.sh now installs OpenJDK 25 (the 2.4.1 release jar
    needs class file version 69), downloads the Freerouting jar to
    /opt/freerouting and writes a headless /usr/local/bin/freerouting
    wrapper. tools/autoroute.py drives the DSN export -> route -> SES
    import round trip through pcbnew; it temporarily de-duplicates reference
    designators because the Specctra exporter refuses the board's duplicate
    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
2026-09-15 Add CLAUDE.md documenting the KiCad tooling and repo rules
    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
2026-09-29 Add Newhaven NHD-2.7-12864WDW3 section to rev-2 OLED plan
    Documents the switch from the Crystalfontz bare panel to the Newhaven
    SSD1322 SPI module: interface/power/mechanical differences, Daisy Seed
    pin budget from the rev-1 netlist (two nets move to free hardware SPI1),
    proposed pin assignment, Daisy Pod breadboard bring-up steps, and the
    open 15V supply question.
    Claude-Session: https://claude.ai/code/session_015uazftScVf1CLS8y5ZtFTR
2026-09-29 Log Trey's pin assignment as Option 2 in the Newhaven OLED section
    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
2026-09-29 Fix the Newhaven screen pin assignment: identical on Pod and rev-2 board
    Replaces the two competing options with one decided assignment
    (D7/D8/D10/D11/D12, matching Trey's list) and the three nets that
    move to make room.
    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
2026-09-29 Remove superseded Option 1/2 comparison from the OLED pin section
    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
2026-09-29 Remove duplicated tail left in OLED pin section
    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
2026-09-30 Add Pod breadboard handover doc for the OLED test firmware repo
    Self-contained brief for a separate firmware project: goal, decided
    3.3V power setup and current-safety measures, full 20-pin module
    wiring, Daisy Pod pin usage, SSD1322 init/RAM-window/framebuffer facts,
    suggested test steps and repo layout.
    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
